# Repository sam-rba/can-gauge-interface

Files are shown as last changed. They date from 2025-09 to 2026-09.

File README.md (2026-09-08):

# Analog Gauge Driver with CAN Interface

Automotive electronic device that drives up to six analog gauges using data from a CAN bus.

## Contents

- `hw/` — Hardware; KiCad files for the PCB.
- `fw/` — Firmare that runs on the PIC microcontroller.
- `sw/` — Software for flashing calibration files onto the device.
- `doc/` — Documentation.

## Features

### Interfaces
- CAN 2.0B interface, up to 500kbps
- Flexible CAN encoding scheme, configurable via CAN

### Outputs
- 1 tachometer output
- 1 speedometer output
- 4 analog outputs (0–5V)

### Power supply
- 9–16V DC input

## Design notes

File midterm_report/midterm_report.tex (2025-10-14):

\documentclass{article}
\usepackage{graphicx}
\usepackage{hyperref}
\usepackage[backend=biber]{biblatex}
\usepackage{amsmath}

\title{\textsc{Comp} 490 Mid-Term Report}

\author{Sam Anthony 40271987 \\
sam@samanthony.xyz \\ s\_a365@concordia.ca
\and
Hovhannes Harutyunyan, PhD \\
Department of Computer Science and Software Engineering \\
haruty@encs.concordia.ca
\and
Concordia University \\
}

\addbibresource{references.bib}

\begin{document}

\maketitle
\tableofcontents
\pagebreak

\section{Project introduction}

The goal of the project is to build an electronic device for use in cars: it is an interface between the car's CAN bus (controller area network) \cite{can20b}, and some analog gauges installed in the cockpit.
An overview of the system is shown in Figure \ref{fig:system}.

\begin{figure}
	\centering
	
	\caption{System diagram.}
	\label{fig:system}
\end{figure}

\section{Desiderata}

The device must be able to perform certain functions.
As well, there are some desirable properties that it should fulfil.

These function and desirable properties are as follows:

\begin{enumerate}
	\item{Receive standard and extended CAN frames from the bus.}
	\item{Decode information in the frames.}
	\item{Generate four analog 0--5V signals suitable for driving temperature or pressure gauges.}
	\item{Generate two variable-frequency square waves for a tachometer and a speedometer.}
	\item{Be user-programmable for any encoding scheme and gauge combination.}
	\item{Run on a 12V automotive electrical power supply.}
	\item{Operate reliably in an automotive environment: resist heat, vibration, and EMI (electromagnetic interference).}
\end{enumerate}

\section{Component selection}

A car is a harsh environment for an electronic device.
The device is subject to large variations in temperature, vibration, and EMI.
To increase reliability, AEC-certified parts were chosen wherever possible.

\subsection{Logic control}

The microcontroller is at the heart of the design.
A Microchip PIC16F1459 was chosen because of its simplicity and robustness, its feature set, and its low cost \cite{pic16f1459}.
It is an 8-bit microcontroller that features a USB peripheral for communicating with the host PC, an SPI peripheral for communicating with the other ICs, and timers for waveform generation.
The PIC is a proven design that Microchip recommends for automotive applications.
It is available in a DIP package, making it convenient for prototyping on a breadboard (Figure \ref{fig:pic}).

\begin{figure}
	\centering
	
	\caption{Microchip PIC16F1459 8-bit microcontroller.}
	\label{fig:pic}
\end{figure}

A Microchip MCP2515 serves as the CAN controller \cite{mcp2515}.
It supports CAN 2.0B up to 1Mbps and it has an SPI interface for communicating with the PIC.
An MCP2561 transceiver goes along with it \cite{mcp2561}.
Like the PIC, both these chips are available in DIP packages for prototyping on the breadboard.

\subsection{Data storage}

The EEPROM is used to store the configuration.
This includes the encoding scheme that defines how parameters are encoded in CAN frames, as well as a table that maps parameter values to output signal values.

There are six such tables: one for each gauge.
Each table has 32 entries, and the mapping is between 16-bit words.
Thus, the required size is $6 \times 32 \times 16 \times 2 = 6144$ bits, or 768 bytes.
The encoding schemes will take a handfull of bytes per gauge in addition.

a Microchip 25LC160C EEPROM was selected.
Its 16Kib (2KiB) of space is more than adequate to hold the configuration.

\subsection{Input/output}

The PIC has an integrated USB peripheral for communicating with a host computer.
The configuration is sent to the PIC via USB and stored on the EEPROM.

Four DACs (digital-to-analog converters) generate analog signals to drive the four pressure or temperature gauges.
Based on the characteristics of commonly-used pressure and temperature sensors \cite{bosch_pst}, it was determined that a resolution of 15mV/step was required.
Given the operating voltage of 5V, this meant that the DACs must have at least $5\text{V}/15\text{mV} \approx 333$ steps of resolution.
Thus, an 8-bit DAC with 256 steps would be insufficient, and so a 10-bit DAC was selected: namely a Microchip\footnote{It is purely a coincidence that all the ICs ended up being Microchip parts. I don't have any particular affinity to the company. It just so happens that they make all the right chips for this particular application.} MCP4912.
The MCP4912 incorporates two DACs in a single chip, so there are two chips per board.

\subsection{Power supply}

The ICs require a 5V supply.

A 12V automotive electrical system operates in a wide range of approximately 9--16V, with a nominal voltage of $\sim$13.7V.
The voltage ripple is often quite significant as well.
Thus, the power supply must be very robust to supply a stable voltage to the ICs.

The voltage drop $V_\text{Drop} = V_\text{In} - V_\text{Out}$ is $16\text{V} - 5\text{V} = 11\text{V}$ in the worst case.
This ruled out the use of a linear regulator, since it would dissipate too much power.
The power dissipation of a linear regulator is linear in $V_\text{Drop}$:

\begin{equation}
	P = (V_\text{In} - V_\text{Out}) \times I
\end{equation}

The load current is estimated to be $\le 250$mA \cite{power_budget}.
That means a linear regulator would dissipate up to $11\text{V} \times 0.250\text{A} = 2.75$W.
That amount of power from a single chip would be difficult to cool.
Thus, a switching regulator is the right choice for this design.

The downside of a switching regulator is that it produces a lot of noise in the PDN (power distribution network).
To isolate the other components from this noise, a two-stage PDN is used.
The first stage is the switching regulator itself, also known as a buck converter.
The buck drops the voltage from 12V down to 7V.

The second stage is composed of two linear regulators: one for the digital circuitry, and one for the analog circuitry.
The linear regulators drop the voltage from 7V down to the final 5V that the ICs require.

Just like a buck converter, switched digital ICs introduce noise into the PDN.
Therefore, it is good practice to keep the digital and analog components separate.
The second power stage isolates the ICs from the noisy buck converter, and splitting the stage between two regulators keeps the digital and analog circuits isolated from one-another.
This design is certainly overkill for the application, but it is better than using too weak of a PDN that delivers an unstable voltage.

The buck converter is a Texas Instruments TPS5430 \cite{tps5430}.
It is surrounded by a couple of LC and RC networks to regulate the voltage and to dampen the output ripple.
See the datasheet and \cite{power_supply} for the process of selecting the accompanying passive components.
The linear regulators are a pair of ST L78M05ABs \cite{l78m}.

\section{PCB design and manufacture}

KiCad was used to design the schematic (Figure \ref{fig:schematic}) and the PCB (Figures \ref{fig:pcb_pours} \& \ref{fig:pcb_3d}).
JLCPCB was chosen to manufacture the printed circuit board.
At the time of writing, the board design has been finalized and submitted to JLC for manufacturing.
It should arrive any day now.

\begin{figure}
	\centering
	
	\caption{Schematic.}
	\label{fig:schematic}
\end{figure}

\begin{figure}
	\centering
	
	\caption{PCB front and back copper pours; drill holes.}
	\label{fig:pcb_pours}
\end{figure}

\begin{figure}
	\centering
	
	\caption{3D render of the PCB.}
	\label{fig:pcb_3d}
\end{figure}

The board is a 4-layer design that uses a combination of surface-mount (SMD) and through-hole (THT) components.
The top and bottom layers are for signals, and the two middle layers are solid ground planes.
This ensures that all signal traces' fields are tightly coupled to ground directly above or below.
Power is routed on the bottom layer.

As mentioned above, most of the ICs are available in DIP (through-hole) packages, and I have been using them for prototyping on the breadboard (Figure \ref{fig:breadboard}).
Once the PCB arrives, I can transplant the chips into the board, along with the passive components.

\begin{figure}
	\centering
	
	\caption{Breadboard circuit for MCP2515 system testing.}
	\label{fig:breadboard}
\end{figure}

The power supply parts, on the other hand, are SMD.
It is important to minimize loop lengths in power supply circuits.
That is why power regulator chips are generally only available in smaller SMD packages.
The SMD components will be assembled by JLC, as I have neither the equipment nor the skill for SMD soldering.

The board was layed out with PCB design best-practices in mind.
Traces are widely-spaced to reduce coupling.
All signal vias are accompanied by a ground via to keep the electric fields from spreading in the dielectric.
All traces are microstripped above a solid ground plane, again to keep the fields tight and to give the current a return path.
The noisy switching regulator is placed far away from the other components to reduce EMI---the sensitive analog signals and the DACs are on the opposite side of the board.

\section{Firmware}

Firmware is the program that runs on the PIC microcontroller.
It is responsible for interacting with the peripherals and transforming data from the CAN bus into output signals for the gauges.

The firmware is written in C for Microchip's XC8 compiler \cite{xc8}.

Each peripheral---MCP2515, 25LC160C, and MCP4912---has a corresponding translation unit.
So far, I have written and tested the MCP4912 DAC unit.
The 25LC160C and MCP2515 units are mostly written but still require more testing.

The firmware must also communicate with a PC via USB.
The Microchip MLA USB library is employed for this purpose \cite{mla_usb}.
However, the USB code uses a lot of the PIC's flash memory.
Some system test builds already fail to link due to lack of space.
As a result, USB may have to be dropped from the project, and another method will have to be devised for programming the user configuration into the EEPROM.
This is a major disappointment, but I will have to work around it seeing as the hardware has already been finalized.

\section{Software}

Software is any program that runs on a host PC, as opposed to on the microcontroller.

I wrote a program called \texttt{usbcom} that communicates with the PIC via USB \cite{usbcom}.
It connects its standard input to the OUT USB endpoint, and its standard output to the IN USB endpoint.
It is written in Go, and uses libusb.

\texttt{usbcom} and the PIC firmware communicate using a proprietary text-based protocol over the USB CDC (communications device class) interface.
The message format is defined using EBNF \cite{protocol}.
The semantics are a simple request-reply arrangement.

I also wrote a Python script---\texttt{bittiming.py}---to calculate CAN bit timing parameters for the MCP2515 \cite{bittiming_py}.

\section{Next steps}

When the board arrives, I will do a visual inspection to ensure that nothing went wrong during manufacturing.
Then I will solder the THT components in place.
Once that is done, I will test the board for continuity and shorts.
With a fully assembled board, I can flash the firmware and migrate system testing from the breadboard to the printed prototype board.
I will finish developing the rest of the firmware, and run through the full suite of system tests that I will have at that point.

I bought some equipment for testing and debugging the system.
A USBtin USB/CAN interface will allow me test the reception of CAN frames \cite{usbtin}.
The EspoTek Labrador is a combined power supply, oscilloscope, and logic analyzer \cite{espotek_labrador}.
It will be used for powering the board and debugging the SPI lines.

If I have time, I would also like to do some experiments with the power supply to see how it handles changes in input voltage.

\printbibliography

\end{document}

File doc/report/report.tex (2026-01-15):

\documentclass[lettersize,conference]{IEEEtran}
\usepackage{biblatex}
\usepackage{hyperref}
\usepackage{graphicx}
\usepackage{subfigure}
\usepackage{pgfgantt}
\usepackage{amsmath,amssymb}
\usepackage{placeins}

\addbibresource{../references.bib}

\title{
	Analog Gauge Driver with CAN Interface \\
	\large \textsc{Comp} 490 Final Report \\~\\
	December 16, 2025
}
\author{
	\IEEEauthorblockN{Sam Anthony}
	\IEEEauthorblockA{Concordia University\\
		Montréal Québec, Canada\\
		Student ID: 40271987\\
		Email: sam@samanthony.xyz}
	\and
	\IEEEauthorblockN{Supervised by Hovhannes Harutyunyan, PhD}
	\IEEEauthorblockA{Concordia University\\
		Department of Computer Science and Software Engineering\\
		Montréal Québec, Canada\\
		Email: haruty@encs.concordia.ca}
}

\begin{document}

\maketitle
\thispagestyle{plain} % enable page numbers
\pagestyle{plain}

\begin{abstract}
	An electronic device is developed that allows analog needle gauges to be retrofitted into a car's EMS (engine management system) while leveraging the capabilities of its CAN (controller area network) bus.
	The proceedings of the project are reported-on, including hardware design, firmware and software development, and testing.
	Finally, the outcomes of the project are assessed against the initial goals, with the overall conclusion being positive.
\end{abstract}

\tableofcontents

\section{Introduction} \label{section:Introduction}

Combustion engines, such as those used to power passenger cars, require precise control over their operation in order to run efficiently and reliably.
Since the early 1970s, car engines have been electronically controlled by an EMS (engine management system) \cite{JapanSemi}.
An EMS is an embedded system consisting of an ECU (electronic control unit), sensors, and actuators.
The actuators include fuel injectors and spark plugs.
The sensors measure crankshaft angle, intake manifold pressure, coolant temperature, and so on.
The ECU features a microcontroller that uses feedback from these sensor data to operate the actuators, thus allowing the engine to run.

Sensor data are used not only by the ECU, but also by a display system mounted in the cabin that allows the driver to monitor the engine's health.
The display system is typically a set of gauges showing, for instance, engine speed, oil pressure, and coolant temperature, among other things.

The display system must visually encode sensor data and convey them to the driver.
Each datum represents the instantaneous value of a continuous quantity---speed, temperature, pressure, etc.
The data are most effectively represented by a graduated radial analog scale with the instantaneous value marked on said scale \cite{Panchal2025}.
The graduated scale takes advantage of vernier acuity: our ability to discern slight misalignment between line segments \cite{Strasburger2018}, while the radial marker leverages the hypercolumnar acuity of vision: our ability to detect minute changes in angle of line segments \cite{Hubel1962}.
Simply put, an analog needle gauge is the best way to display information to the driver.
That is why even modern digital display systems are often skeuomorphs of analog gauges, as seen in Fig.~\ref{fig:Stack}.

\begin{figure}
	\centering
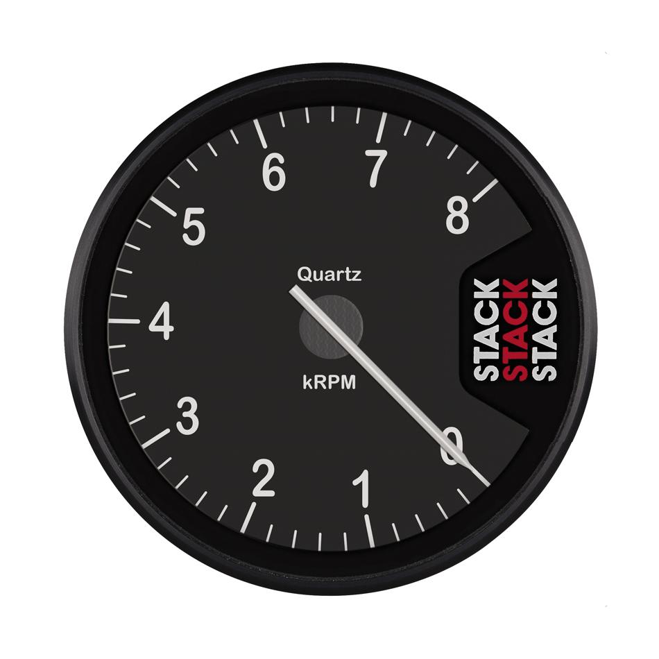
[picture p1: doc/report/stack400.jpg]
	\subfigure[]{ \label{subfig:Stack400}}
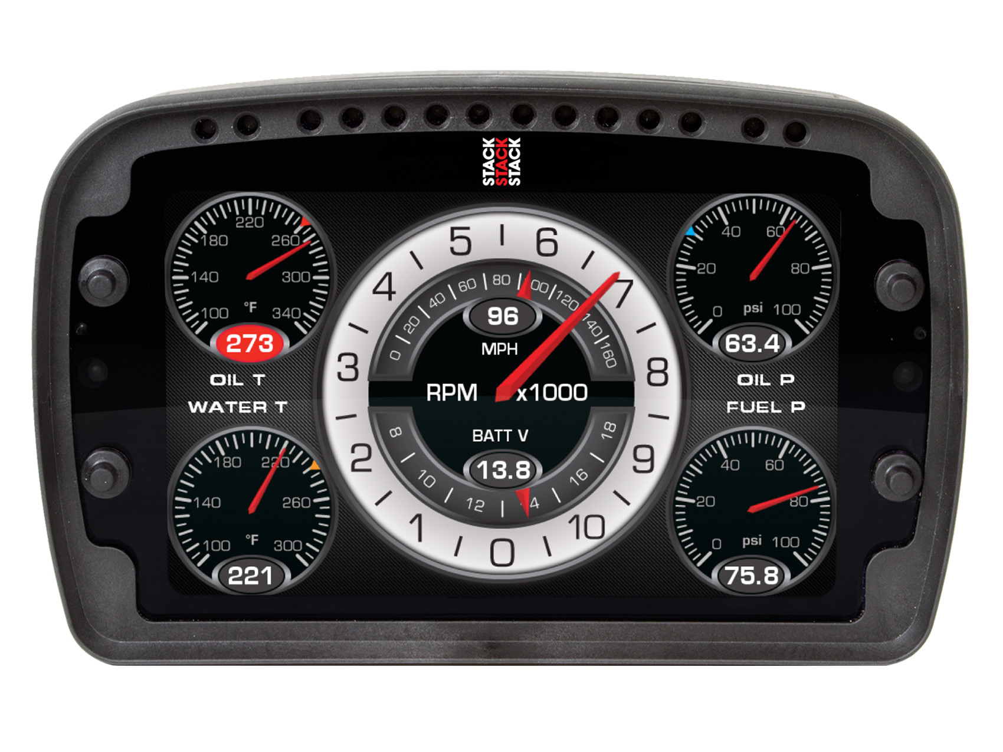
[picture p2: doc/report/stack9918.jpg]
	\subfigure[]{ \label{subfig:Stack9918}}
	\caption{\subref{subfig:Stack400} Analog needle gauge \cite{Stack400} and; \subref{subfig:Stack9918} skeuomorphic digital display emulating analog gauges \cite{Stack9918}.}
	\label{fig:Stack}
\end{figure}

As engine performance increases, the operating window where it will run reliably shrinks, necessitating even tighter control.
This spurs demand for even more sensor data, both for the ECU---to precisely regulate the running of the engine---and for the driver, to monitor the engine's health and to ensure that it stays within its safe operating window.

This is especially true in racing, where the engine must be fine-tuned to its limits while remaining reliable for the duration of its life.
Race teams often fit additional sensors and gauges to the car in order to monitor the health of the engine (Fig.~\ref{fig:R31}).

\begin{figure}
	\centering
	
	\caption{Analog gauges fitted to 1987 Nissan Skyline GTS-R Group A race car \cite{r31}.}
	\label{fig:R31}
\end{figure}

All these sensor data must somehow be transmitted throughout the car; a computer network handles this task well.
CAN (controller area network) \cite{can20b} is ubiquitous: introduced by Bosch in the early 1990s and standardized by ISO 11898 \cite{CanHistory}, all cars sold in the United States are required to be equipped with a CAN bus \cite{CFR40.86.1806-05}.

Most modern digital display systems, such as the one shown in Fig.~\ref{subfig:Stack9918}, come with a CAN interface, allowing them to display a practically unlimited array of information from whatever sensors may be equipped to the car.
On the other hand, analog gauges have largely been abandoned by manufacturers, as digital panels can display myriad information at a fraction of the cost of an equivalent set of analog gauges.
However, some, including myself, prefer a genuine analog gauge as opposed to a facsimile displayed on a screen.
The trouble is, most analog gauges lack a CAN interface, with only a few companies making CAN-enabled analog gauges, mostly for industrial applications \cite{Vdo}.

Those who wish to install an analog gauge typically do so by installing a sensor on the engine and running a wire directly to the gauge's analog input---this is the setup recommended by most gauge manufacturers \cite{Stack3307Manual}.
While this does work, it is less than ideal for several reasons.

Firstly, running a wire through the engine bay leaves the signal vulnerable to EMI (electromagnetic interference) as it travels near noisy components like the ignition coils.
This can cause signal integrity issues that can otherwise be avoided by transporting the signal via the CAN bus that the car is likely to have already---CAN uses a CRC (cyclic redundancy check) to provide data integrity.

Secondly, the EMS already features a host of sensors, and installing another for the gauge often leads to duplication.
While this may appear to provide redundancy, it in fact does not.
On the contrary, it reduces reliability and increases complexity by introducing additional failure points into the system.
A properly engineered solution would integrate the gauge into the EMS, allowing them to share sensor data, thus reducing the complexity of the system.

This brings us finally to the subject of the report: a device that allows analog gauges to be retrofitted into a car while leveraging the capabilities of the CAN bus already present in the vehicle.

\section{Project Overview} \label{section:ProjectOverview}

At a high level, the device acts as an interface between the car's EMS and the analog gauges in the cabin.
It receives sensor data encoded in CAN frames from the ECU, and transforms them into signals that the gauges can understand: such as a variable-frequency square wave for a tachometer, or a 0--5V analog signal for a pressure gauge.
Thus, it is referred to as an \emph{analog gauge driver with a CAN interface}.

A block diagram of the system is shown in Fig. \ref{fig:BlockDiagram}.
The device has a CAN controller and transceiver for sending and receiving CAN frames.
A microcontroller decodes and extracts sensor data from the frames, and communicates the data to the peripherals which drive the gauges.
Two dual DACs (digital-to-analog converters) generate signals for the four analog outputs.
These can drive up to four temperature or pressure gauges, or any gauge that accepts a 0--5V analog input.
The microcontroller's timers produce two variable-frequency square waves which drive the tachometer and speedometer.

\begin{figure}
	\centering
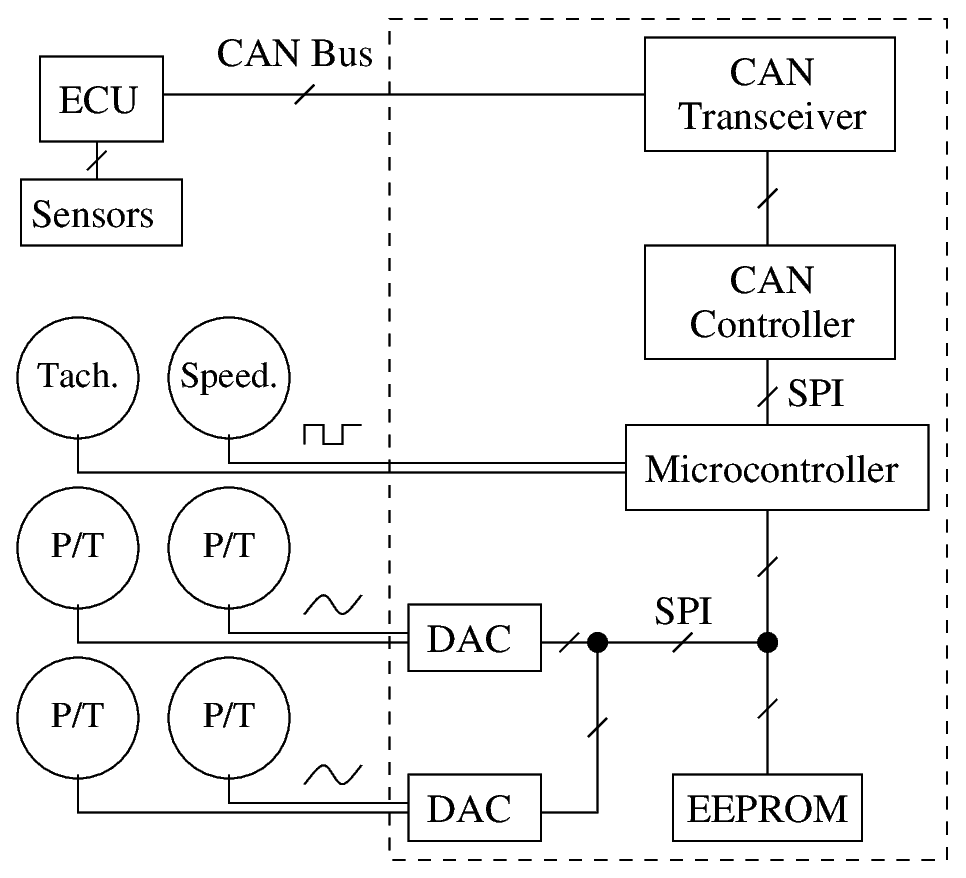
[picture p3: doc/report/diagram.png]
	
	\caption{System diagram.}
	\label{fig:BlockDiagram}
\end{figure}

As it is intended to be a generic part that can be retrofitted to existing cars, the device must work with any combination of sensors, gauges, and CAN encoding schemes.
Thus, it is user-programmable, allowing it to be installed in any system.
The user-calibration is programmed via CAN and stored in non-volatile memory, namely an EEPROM (electrically erasable programmable read-only memory) chip.

The project consisted of four tasks that were completed concurrently over the course of the term.
The timeline of the project is shown in Fig. \ref{fig:Timeline}.
The tasks to be completed were hardware design, firmware development, software development, and testing.
Each of these topics are covered in the subsequent sections.

\begin{figure*}[p]
	\centering
	\begin{ganttchart}[
		x unit=0.055in,
		y unit title=0.3in,
		y unit chart=0.275in,
		newline shortcut=true,
		bar label node/.append style={align=left},
		milestone label node/.append style={align=left},
		vrule label node/.append style={align=center},
		time slot format=isodate
	]{2025-09-01}{2025-12-18}
		\gantttitlecalendar{year, month=name} \\

		\ganttgroup{Hardware}{2025-09-01}{2025-10-22} \\
		\ganttbar{PCB design}{2025-09-01}{2025-10-01} \\
		\ganttlinkedbar{Manufacturing}{2025-10-01}{2025-10-15} \\
		\ganttlinkedbar{Board testing}{2025-10-15}{2025-10-22} \\
		\ganttlinkedmilestone{Board completed}{2025-10-22} \\

		\ganttgroup{Firmware}{2025-09-04}{2025-11-10} \\
		\ganttbar{Main}{2025-09-04}{2025-11-10} \\
		\ganttbar{DAC}{2025-10-02}{2025-11-08} \\
		\ganttbar{EEPROM}{2025-10-02}{2025-11-08} \\
		\ganttbar{CAN}{2025-10-03}{2025-11-08} \\
		\ganttmilestone{Migrate to board}{2025-10-22} \\
		\ganttbar{Calibration}{2025-10-24}{2025-11-08} \\
		\ganttbar{Serialization}{2025-11-01}{2025-11-08} \\
		\ganttbar{Decoding}{2025-11-01}{2025-11-08} \\
		\ganttbar{Tach./speedo.}{2025-11-10}{2025-11-10} \\

		\ganttgroup{Software}{2025-10-03}{2025-11-10} \\
		\ganttbar{CAN timing script}{2025-10-03}{2025-10-04} \\
		\ganttbar{Calibration software}{2025-11-07}{2025-11-10} \\

		\ganttgroup{Testing}{2025-09-04}{2025-11-10} \\
		\ganttmilestone{First SPI test}{2025-10-02} \\
		\ganttmilestone{First DAC test}{2025-10-02} \\
		\ganttmilestone{First EEPROM test}{2025-10-02} \\
		\ganttmilestone{First CAN test}{2025-10-23} \\
		\ganttmilestone{First calibration}{2025-11-08} \\
		\ganttmilestone{First tach./speedo.\ganttalignnewline{}signals}{2025-11-10} \\

		\ganttgroup{Documentation}{2025-09-01}{2025-12-18} \\
		\ganttbar{Power supply}{2025-09-07}{2025-09-27} \\
		\ganttbar{Midterm report}{2025-10-13}{2025-10-14} \\
		\ganttbar{Cal. frame format}{2025-10-25}{2025-11-08} \\
		\ganttbar{Final report}{2025-12-08}{2025-12-18}

		\ganttvrule{Board completed}{2025-10-22}
	\end{ganttchart}
	\caption{Project timeline.}
	\label{fig:Timeline}
\end{figure*}

\section{Hardware} \label{section:Hardware}

The hardware is a PCB (printed circuit board) hosting a set of ICs (integrated circuits)---the microcontroller and peripherals listed in the previous section (Fig \ref{fig:BlockDiagram})---and some supporting passive components: resistors, capacitors, and an inductor.

\subsection{Component selection} \label{subsection:ComponentSelection}

A car is a harsh environment.
The device is subject to vibration, EMI (electromagnetic interference), and large variations in temperature.
To increase reliability, AEC-certified parts were chosen wherever possible \cite{aec}.

\paragraph*{Microcontroller}
The microcontroller is at the heart of the design.
A Microchip PIC16F1459 was chosen for its simplicity, robustness, feature-set, and low cost%
\footnote{ \label{foot:Usb}
	The PIC16F1459 also features a USB (universal serial bus) interface.
	The original design, as shown in the proposal \cite{proposal}, used USB to program the user-calibration.
	However, later in the project, USB had to be dropped due to memory constraints; now the calibration is programmed via CAN.
	In a future revision of the board, the PIC16F1459 could be replaced with a chip lacking a USB interface in order to reduce cost.}
\cite{pic16f1459}.
It is an 8-bit microcontroller with an SPI peripheral for communicating with the other ICs, and timers for generating the tachometer and speedometer signals.
The PIC is a proven design that Microchip recommends for automotive applications.
It is available in a DIP (dual in-line) package, making it convenient for breadboard prototyping (Fig. \ref{fig:Breadboard}).

\begin{figure}
	\centering
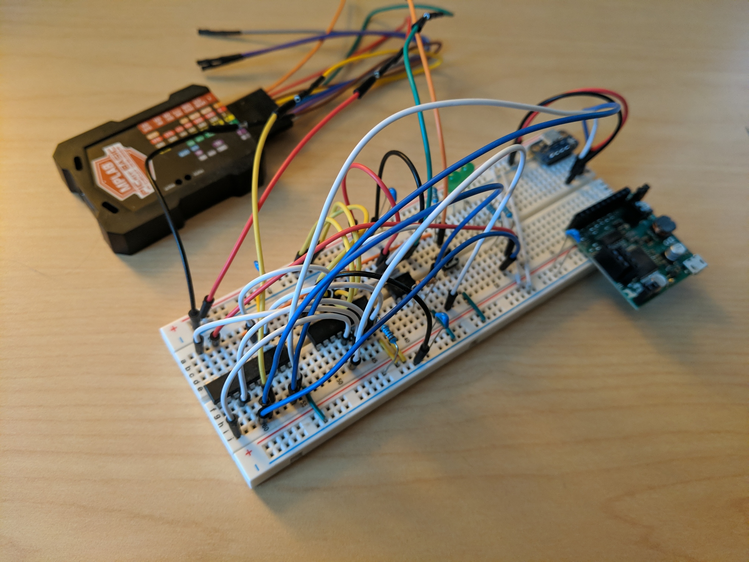
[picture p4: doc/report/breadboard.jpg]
	
	\caption{Breadboard circuit for CAN testing.}
	\label{fig:Breadboard}
\end{figure}

\paragraph*{CAN controller and transceiver}
The CAN controller handles the reception and transmission of CAN frames.
It is complemented by a CAN transceiver which acts as a buffer between the controller's logic level signals and the differential signals on the bus.
A Microchip MCP2515 controller \cite{mcp2515} and MCP2561 transceiver \cite{mcp2561} were chosen to fill these roles.
The MCP2515 supports CAN 2.0B up to 1Mbps and it has an SPI interface for communicating with the PIC.
Both these chips are available in DIP packages for breadboard prototyping.

\paragraph*{EEPROM}
The EEPROM stores the user-calibration that defines how sensor signals are encoded in CAN frames, as well as tables that map sensor readings to output signal values.
A Microchip 25LC160C EEPROM was selected \cite{25lc160c}.
It has an SPI interface, and its 2KiB of space is sufficient to store  the calibration.

\paragraph*{DACs}
Two dual-channel DACs (digital-to-analog converters) drive the four analog outputs of the board.
Based on the characteristics of commonly-used pressure and temperature sensors \cite{bosch_pst}, it was determined that a resolution of 15mV/step was required.
Given the operating voltage of 5V, this meant that the DACs would need at least $5\text{V}/15\text{mV} \approx 333$ steps of resolution.
Thus, an 8-bit DAC with 256 steps would have been insufficient, and so a 10-bit DAC was selected: namely a Microchip MCP4912%
\footnote{
	Perhaps it is worth noting that I have no particular affinity to Microchip as a company.
	It is purely a coincidence that all the chosen ICs ended up being made by them.
	It just so happens that they make good chips for this application.}
\cite{mcp4912}.
The MCP4912 is a dual-channel 10-bit DAC, so two of them are required to drive the board's four analog outputs.

\subsection{Power supply} \label{subsection:PowerSupply}

Standard automotive electrical systems operate at a nominal voltage of around 13.7V, but can swing between 9 and 16V.
The voltage supply often has a strong pulsating component as well, known as ripple.
The board's ICs require a stable 5V to operate reliably.
Hence, the board's power supply is very robust to tolerate the wide input voltage range and to rectify the ripple.

The voltage drop $V_\text{Drop} = V_\text{In} - V_\text{Out}$ is $16\text{V} - 5\text{V} = 11\text{V}$ in the worst case.
This ruled out the use of a linear regulator, since it would dissipate too much power---the power dissipation of a linear regulator is linear in $V_\text{Drop}$: $P = V_\text{Drop} \times I$.
The load current was estimated to be 250mA at most \cite{power_budget}, so a linear regulator would dissipate up to 2.75W.
That amount of power from a single chip would be difficult to cool.
Therefore, a linear regulator was deemed inadequate, necessitating the use of a switching regulator instead.

The downside of a switching regulator is that it introduces noise and ripple into the PDN (power distribution network).
To isolate the other components, a two-stage PDN is used.

The first stage is the switching regulator itself, also known as a buck converter.
It drops the voltage from the car's 9--16V down to an intermediate 7V level.

Just like a buck converter, switching digital ICs introduce noise into the PDN.
Therefore, the second stage is split between two regulators in order to keep the analog and digital circuitry separate.
It is composed of two ST L78M05AB \cite{l78m} LDOs (low-dropout regulators) that bring the voltage from 7V down to the final 5V that the ICs require.

A diagram of the PDN is shown in Fig. \ref{fig:Pdn}.

\begin{figure}
	\centering
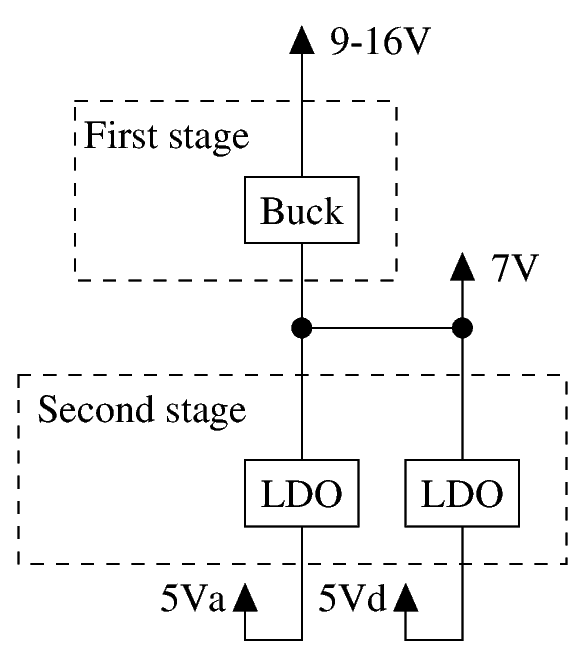
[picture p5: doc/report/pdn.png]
	
	\caption{Power distribution network.}
	\label{fig:Pdn}
\end{figure}

The buck converter in the first stage is a Texas Instruments TPS5430 \cite{tps5430}.
It is accompanied by some RC and LC networks that set the output voltage level and dampen the output ripple.
Unfortunately, the passive component values were calculated incorrectly, which resulted in the buck converter outputting the wrong voltage.
This mistake is discussed further in \S\ref{section:Testing}.

\subsection{PCB design and manufacture} \label{subsection:PcbDesign}

The schematic (Fig. \ref{fig:Schematic}) and PCB (Figs. \ref{fig:PcbPours}, \ref{fig:Pcb3d}, and \ref{fig:PcbAssembled}) were designed in KiCad \cite{kicad}.
JLCPCB manufactured the PCB \cite{jlcpcb}.

\begin{figure*}
	\centering
	
	\caption{Schematic.}
	\label{fig:Schematic}
\end{figure*}

\begin{figure}
	\centering
	
	\caption{PCB front and back copper pours.}
	\label{fig:PcbPours}
\end{figure}

\begin{figure}
	\centering
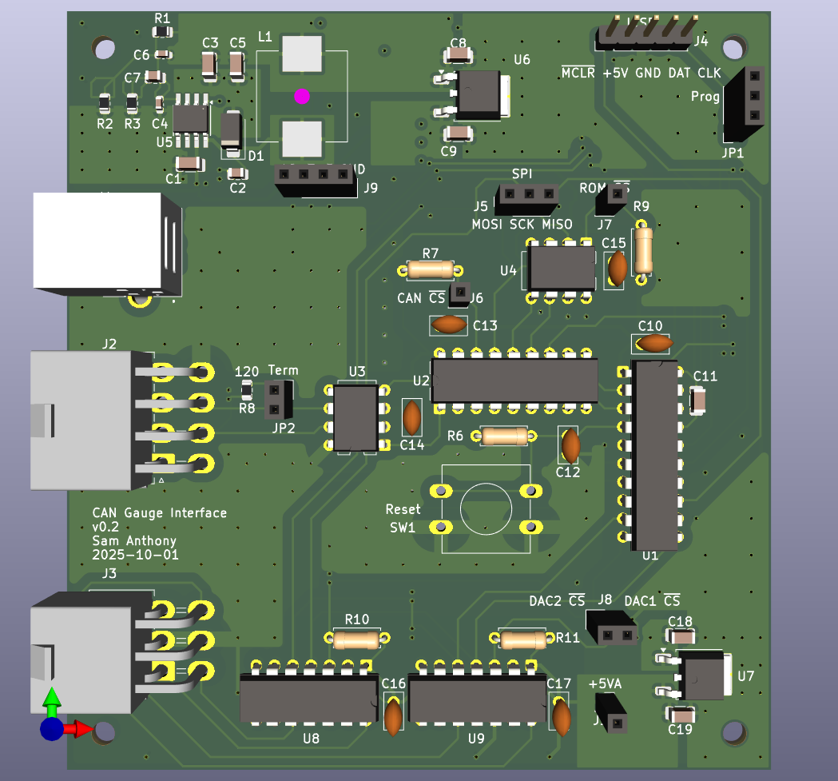
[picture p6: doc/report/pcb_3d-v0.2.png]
	
	\caption{3D render of the PCB. Note the vestigial USB-B connector in the top left, to be removed in a future revision (see footnote \ref{foot:Usb}).}
	\label{fig:Pcb3d}
\end{figure}

\begin{figure}
	\centering
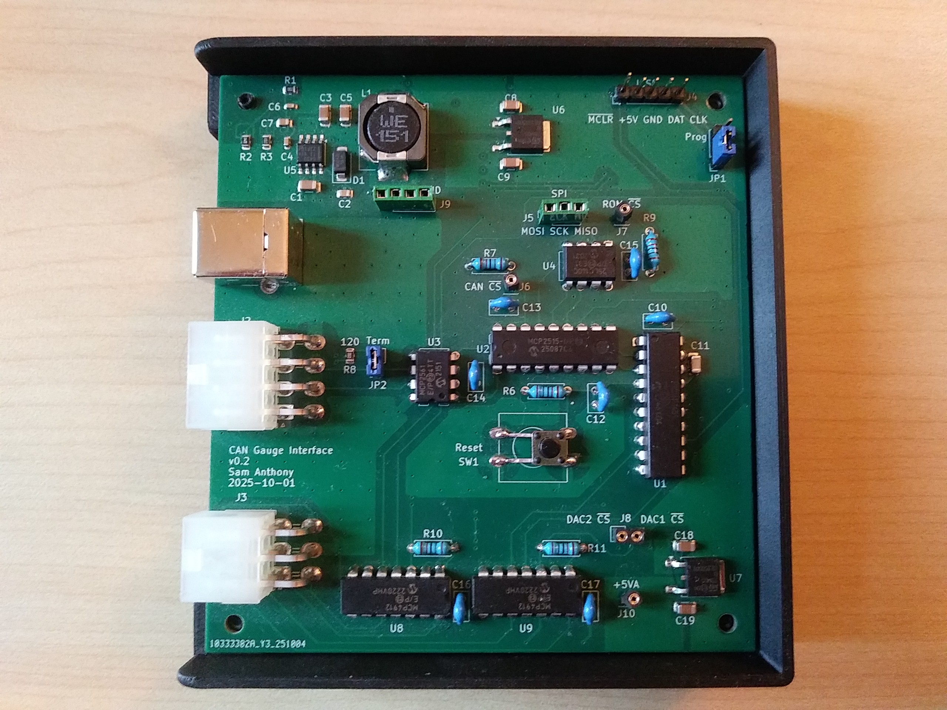
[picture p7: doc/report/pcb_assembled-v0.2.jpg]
	
	\caption{Fully-assembled PCB sitting on 3D-printed stand.}
	\label{fig:PcbAssembled}
\end{figure}

The board was laid out with PCB design best-practices in mind.
It is a 4-layer design that uses a combination of surface-mount (SMD) and through-hole (THT) components%
\footnote{
	Not that mixing SMD and THT components is good practice---it is not.
	The board was only designed this way to allow the DIP parts that were used on the breadboard to be reused on the prototype PCB.}.
The top and bottom layers are for signals, and the two middle layers are solid ground planes; power is routed on the bottom layer.
All traces are microstripped above a solid ground plane to keep the fields tightly coupled and to give the current a low-impedance return path.
All signal vias are accompanied by a ground via, again to keep the fields from spreading out in the dielectric.
Traces are widely-spaced to reduce interference with one another.
The noisy switching regulator is placed far away from the other components to reduce EMI---the sensitive analog signals and the DACs are on the opposite side of the board.

One may notice that the board sports a USB-B connector: a vestige of the original design which used USB for user-calibration, as opposed to CAN which it uses currently (see footnote \ref{foot:Usb}).
The connector is no longer required and will be removed in a future revision.

As mentioned above, most of the chosen ICs are available in DIP (through-hole) packages, and were used for prototyping on a breadboard (Fig. \ref{fig:Breadboard}).
They were then transplanted into the PCB once it had been manufactured (Fig. \ref{fig:PcbAssembled}).
This allowed firmware development to be carried out in parallel on the breadboard while waiting for the PCB to arrive, as the timeline in Fig. \ref{fig:Timeline} shows.

\section{Firmware} \label{section:Firmware}

Firmware is the program that runs on the board's microcontroller.
It is responsible for interacting with the peripherals, decoding CAN frames, and transforming sensor data into output signal levels to drive the gauges.
It is written in ISO~C (C99) \cite{c99}.
The program is compiled for the PIC16F1459 using Microchip's XC8 compiler \cite{xc8}.
In total, the firmware is 1601 lines of C code \cite{repo}.

The firmware is divided into a set of C modules.
Each peripheral (MCP2515, 25LC160C, MCP4912) has a corresponding module (\texttt{can}, \texttt{eeprom}, \texttt{dac}).
Collectively, these are known as the HAL (hardware abstraction layer).

There are also higher-level modules that make use of the HAL.
One example is the \texttt{table} module.
The EEPROM stores several tables that are mappings from sensor-reading-values to output-signal-values.
For example, one table maps engine speed (rpm) to tachometer pulse frequency.
The \texttt{table} module makes use of the \texttt{eeprom} HAL module and provides a simple interface to read and manipulate these tables stored in the EEPROM.

Dependencies between the modules are shown in Fig. \ref{fig:Deps}.

\begin{figure}
	\centering
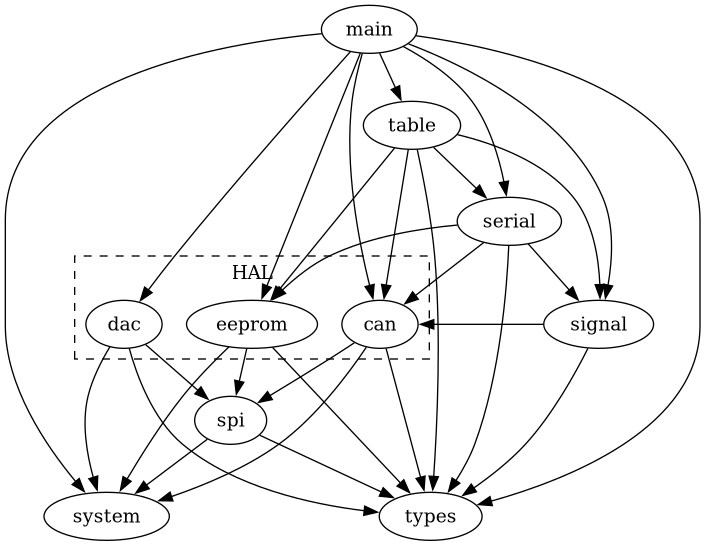
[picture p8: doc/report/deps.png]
	
	\caption{Firmware module dependency graph.}
	\label{fig:Deps}
\end{figure}

The \texttt{main} entry point of the firmware simply initializes the HAL and waits to receive an interrupt from either the CAN controller or a timer.

The ISR (interrupt service routine) handles the reception and decoding of CAN frames.
Upon receiving a frame, the ISR decodes the sensor signal contained therein, and looks up the corresponding output signal value in the mapping table.
It then directs one of the peripherals to generate the appropriate output signal accordingly.
For instance, it may instruct one of the DACs to change the voltage being driven to a temperature/pressure gauge, or it may set the period of the tachometer wave.

The variable-frequency square waves that drive the tachometer and speedometer are generated using the PIC's built-in timer peripherals.
Upon overflow, the timers trigger the ISR to toggle the appropriate GPIO (general-purpose input/output) pin.
The waves' frequencies are controlled by setting the timers' periods.

\subsection{Calibration} \label{subsection:FwCalibration}

In order for the device to work with any combination of sensors, gauges, and CAN encoding schemes, it must be configurable by the end-user.

The user-calibration defines the mapping between sensor readings and output signal values that drive the gauges.
It also defines how sensor readings are encoded in CAN frames.

The \texttt{signal} module defines a data structure that specifies the format of a sensor reading, or \emph{signal} as it is known in the DBC format \cite{dbc10}, within the payload of a CAN frame.
This includes the CAN ID of the carrier frame, the size and offset of the signal within the frame's payload, and the byte order of the signal.

The format of each signal is stored in the EEPROM as part of the user-calibration.
The calibration includes six signals: tachometer, speedometer, and the four analog channels.

The user-calibration is programmed onto the board via special CAN frames, called \emph{calibration} or \emph{control} frames.
There are two control frames, each with a unique ID.
The first is the \emph{table control frame} which is used to read or write rows of the mapping tables.
The second is the \emph{signal control frame} which is used to read or write the encoding format of each signal.
These control frames are defined in full by the \emph{calfmt} document in the project's source repository \cite{calfmt}.

When the device receives a control frame, the ISR decodes it and either, in the event of a write-request, updates the appropriate segment of the calibration in the EEPROM; or in the event of a read-request, reads the appropriate segment and responds by sending it back in a CAN frame.
This allows the calibration to be flashed onto the board using write requests and verified using read requests.
The calibration is sent to the device from a personal computer running the calibration software, which is discussed in the next section.

\section{Software} \label{section:Software}

In addition to the firmware, several other pieces of software were developed over the course of the project.
In contrast with the firmware which runs on the device's microcontroller, these programs target a personal computer.

\subsection{Calibration software} \label{subsection:SwCalibration}

As described above, the user-calibration, stored in the board's EEPROM, allows the device to be configured for any combination of sensors, gauges, and CAN encoding schemes.

The \emph{cal} program flashes the calibration from a personal computer onto the device via the CAN bus \cite{Cal}.
Cal takes a set of files containing the user-calibration as input, and outputs CAN frames that are sent to the device.
These are the special \emph{control} frames mentioned in \S\ref{subsection:FwCalibration} and defined fully in \cite{calfmt}.

The calibration is represented by a DBC file \cite{dbc10} and a set of CSV files.
The DBC file specifies the CAN encoding scheme which defines how sensor readings, called \emph{signals} in the DBC file, are encoded into CAN frames.
The DBC file can specify one signal for each gauge, e.g., \texttt{EngineSpeed} for the tachometer, \texttt{EngineOilPressure} for one of the analog gauges, and so on, each with a corresponding CAN ID and encoding format.
This allows the device to be configured for the CAN encoding scheme that the car's EMS uses.

The CSV files define the tables that map sensor-reading-values to output-signal-values.
There is one table, and thus one CSV file, for each signal.
This allows the device to be configured for the particular sensors and gauges installed in the car.

Cal is written in 674 lines of Go \cite{Golang}.
It uses the Linux kernel's SocketCAN \cite{SocketCan} facility to access the CAN bus.
Thus, its support is limited to Linux only.
Ideally it should be ported to other operating systems in the future.

\subsection{CAN bit timing calculation} \label{subsection:Bittiming}

The second program is a small script for calculating CAN bit timing parameters.

Each node in a CAN network has its own clock generator.
The bit timing parameters can be configured individually at each node in order to achieve a common bit rate throughout the network even though the nodes' clock periods may be slightly out of sync \cite{CanBitTiming}.

The script, named \texttt{bittiming.py} \cite{BitTimingScript}, calculates a set of valid combinations of timing parameters for a given clock frequency and bit rate.
It displays these parameter combinations in the form of configuration words for the MCP2515 CAN controller.

The configuration words are hard-coded in the firmware and are written to the MCP2515's configuration registers at startup time.
Although the bit rate is currently a constant set at compile time, the firmware includes several sets of bit timing configuration words, one for each commonly-used bit rate as defined by CANopen \cite{CanBitrates}.
This is to facilitate the addition of an automatic baud rate detection algorithm to the firmware at a later date.

A flaw in the board was discovered while calculating the bit timing parameters.
The CAN controller requires an external oscillator.
On the prototype board, the CAN controller's clock input is connected to the microcontroller's clock output which runs at 12MHz.
12MHz is not fast enough to run a bit rate of 800kbps or greater.
Therefore, although the MCP2515 supports bit rates up to 1Mbps, the board is limited to 500kbps with the current clock setup.
This can be remedied in a future revision by adding a dedicated 20MHz oscillator for the CAN controller.

\section{Testing} \label{section:Testing}

A suite of tests was developed to verify the functionality of the device.
Each system test is a standalone firmware image designed to test a particular subsystem.
For example, there are system tests for the CAN, DAC, and EEPROM modules, and for the tachometer and speedometer signal generation systems.
There are also several unit tests to verify some of the more complex routines, such as the CAN decoding functions.
The tests were used continually throughout the project to check the functionality of each firmware module as they were being developed, and to detect regression as changes were made and new modules added.

\subsection{Equipment} \label{subsection:TestEquipment}

Some special equipment was required for testing.

A USBtin USB-to-CAN interface enabled reading and writing CAN frames to the bus from a workstation computer \cite{usbtin}.
It was used to monitor the bus during CAN system testing, and to flash the user-calibration onto the device.

An EspoTek Labrador is an inexpensive all-in-one oscilloscope, signal generator, power supply, and logic analyzer \cite{espotek_labrador}.
It proved invaluable during testing.
The power supply provided 12V to the board.
The logic analyzer was used to debug the SPI (serial peripheral interface) bus while developing the HAL firmware modules.
And the oscilloscope was used to measure the tachometer and speedometer signals generated by the device.

Finally, a simple multimeter was used for continuity testing to verify the design of the circuit board, and to measure the voltages of the board's analog outputs during system testing.

\subsection{Results} \label{subsection:TestResults}

An issue with the power supply was uncovered while testing the circuit board.
As mentioned in \S\ref{subsection:PowerSupply}, the first stage of the power supply is supposed to output 7V.
However, upon receiving the board, this rail measured only 5V, revealing a mistake in the calculation of the passive components surrounding the buck converter that control its output voltage.
While this issue will have to be corrected in a future revision, it did not prevent the existing board from being used for the remainder of the project.
Bypassing the second stage of the power supply by jumping the 7V and 5V rails, thus providing the ICs with the correct voltage, allowed the board to function well enough.
This workaround can be seen in Fig. \ref{fig:TestSetup}.

\begin{figure}
	\centering
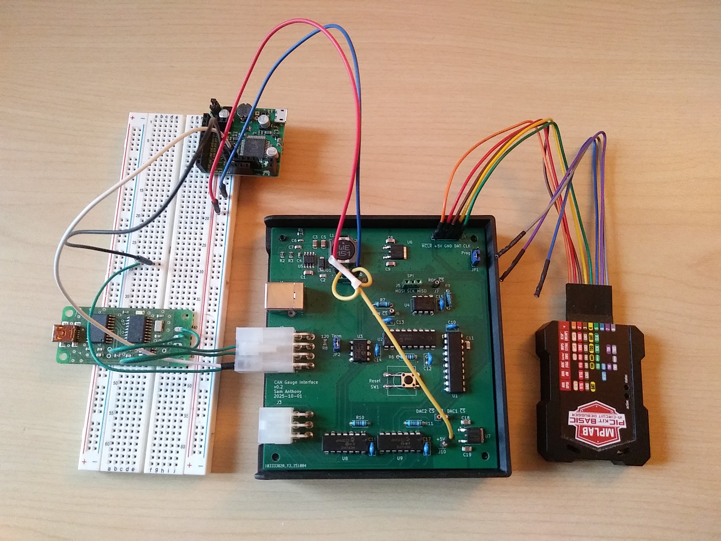
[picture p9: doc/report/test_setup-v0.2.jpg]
	
	\caption{%
		Testing setup: EspoTek Labrador (top), USBtin (left), gauge driver (center), PIC programmer (right).
		Yellow wire jumps the 7V, 5V-analog, and 5V-digital rails, providing power to the board and circumventing the flaw in the first stage of the power supply.}
	\label{fig:TestSetup}
\end{figure}

Overall, testing has been successful.
Despite minor flaws in the board, the device is able to perform all of its duties.
It is able to receive CAN frames from the bus, decode them, and generate signals to drive up to six analog gauges accordingly.
It can generate two variable-frequency square waves to drive a tachometer and a speedometer, and four 0--5V analog signals to drive four pressure or temperature gauges.
Furthermore, it can be configured for any combination of sensors, gauges, and CAN encoding schemes by flashing a user-calibration with the \emph{cal} program.

\section{Conclusion} \label{section:Conclusion}

In conclusion, the project was a success; the device fulfills all of its requirements.
What follows is a summary of the goals, proceedings, and outcomes of the project.

The goal was to design an electronic device that would allow analog gauges to be retrofitted into a car's EMS (engine management system) while leveraging the capabilities of the car's CAN (controller area network) bus.
The device transforms sensor reading data from the CAN bus into electric signals suitable for driving the gauges.

In the first phase of the project, the device's hardware was designed: a PCB (printed circuit board) hosting a set of ICs (integrated circuits) that, together as a system, perform the necessary functions of the device.

Firmware---software that runs on the device's microcontroller---was developed to operate the device's hardware.
The firmware is responsible for interacting with the various peripherals on the board, decoding CAN frames, and transforming the sensor data contained therein into output signal values to drive the gauges.

In addition to the firmware, another piece of software was developed: a program for flashing a user-calibration onto the device.
This program, called \emph{cal}, reads the calibration from a set of files and writes it to the device via the CAN bus.
The calibration allows the device to be configured for any combination of sensors, gauges, and CAN encoding schemes that the car's EMS may use.

Both the software and hardware of the device were tested continually over the course of the project.
Suites of unit and system tests were developed to verify the device's subsystems and firmware modules.
Hardware testing revealed some flaws in the board that will have to be fixed in a subsequent revision.
However, they were not catastrophic, and development was able  to proceed using the existing board.

Ultimately, testing confirmed that, despite minor flaws in the board, the device operates correctly and fulfills all of its requirements.
It is able to receive CAN frames from the bus, decode them, and generate signals to drive up to six analog gauges.
Furthermore, it can be configured for any combination of sensors, gauges, and CAN encoding schemes by flashing a user-calibration with the \emph{cal} program.
Hereby the project is considered a success.

\FloatBarrier
\clearpage
\printbibliography
\vfill

\end{document}

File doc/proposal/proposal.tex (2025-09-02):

\documentclass{article}
\usepackage{graphicx}

\title{
Analog Gauge Driver with CAN Interface \\
\large COMP490 Project Proposal
}
\author{
Sam Anthony 40271987 \\
sam@samanthony.xyz \\ s\_a365@concordia.ca
\and
Hovhannes Harutyunyan, PhD \\
Department of Computer Science and Software Engineering \\
haruty@encs.concordia.ca
\and
Concordia University \\
}

\begin{document}

\maketitle

Installing aftermarket gauges in a car typically requires installing sensors as well.
However, such sensors are often already present, and are used by the ECU (engine control unit).
Thus, the installation of aftermarket gauges can result in duplicate sensors which add complexity without augmenting the functionality or reliability of the vehicle.
Sensors installed like this are not redundant.
In fact, they reduce reliability, because each is a single point of failure.

The proposed device allows gauges to use the sensors already on the car.
It retrieves sensor data from the ECU via the CAN bus (controller area network bus) and transforms the data into a format that the gauges can understand: a 0--5V analog signal in the case of a temperature or pressure gauge, or a square wave in the case of a tachometer or speedometer.

The device is an embedded system comprising a microcontroller, a CAN controller and transceiver, several DACs (digital-to-analog converters), and PROM (programmable read-only memory).
The CAN interface is used for retrieving data from the ECU via the bus.
The DACs drive analog signals to the temperature and/or pressure gauges.
The microcontroller has an integrated PWM peripheral for driving a square wave to the tachometer and/or speedometer.
The PROM stores the calibration: a table that maps CAN data values to voltages or frequencies.
The microcontroller has a USB interface for programming the PROM from a computer.

\begin{figure}
	
	\caption{System diagram}
\end{figure}

The project has three parts: hardware design, software development, and testing.
The hardware and software development can be carried out concurrently.
Testing is the final step.

Hardware design involves selecting ICs (integrated circuits), creating a circuit schematic, and designing a PCB (printed circuit board).
Once the board design is finalized, it can be sent for manufacturing.

Two pieces of software must be written.
The first runs on the microcontroller.
Essentially, it must communicate with the various peripherals by transforming and transferring data between them.
It must fetch frames from the CAN controller and decipher them.
The CAN data are used to lookup the output value in the ROM.
Either the PWM peripheral or a DAC is used to send the appropriate signal to the gauge.
The microcontroller uses SPI (serial peripheral interface) to communicate with the peripherals.

The second piece of software runs on the user's computer.
It programs the PROM with calibration data.
It communicates with the microcontroller using a simple text-based protocol over USB.

\end{document}

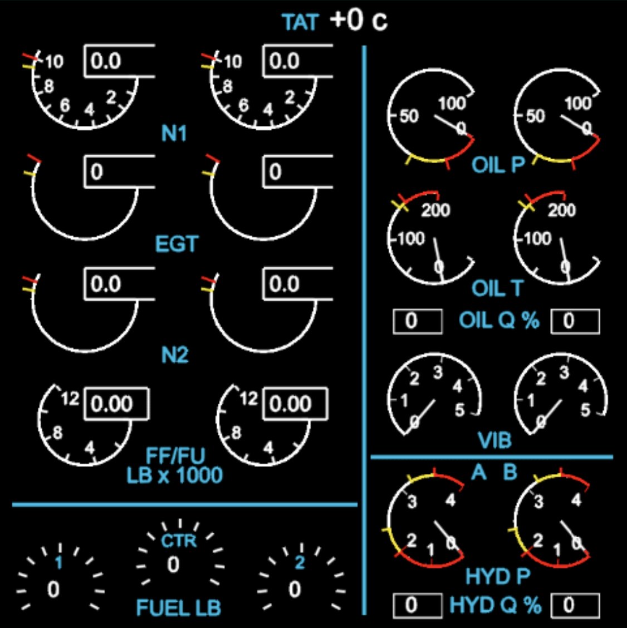
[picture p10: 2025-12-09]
doc/report/boeing.jpeg

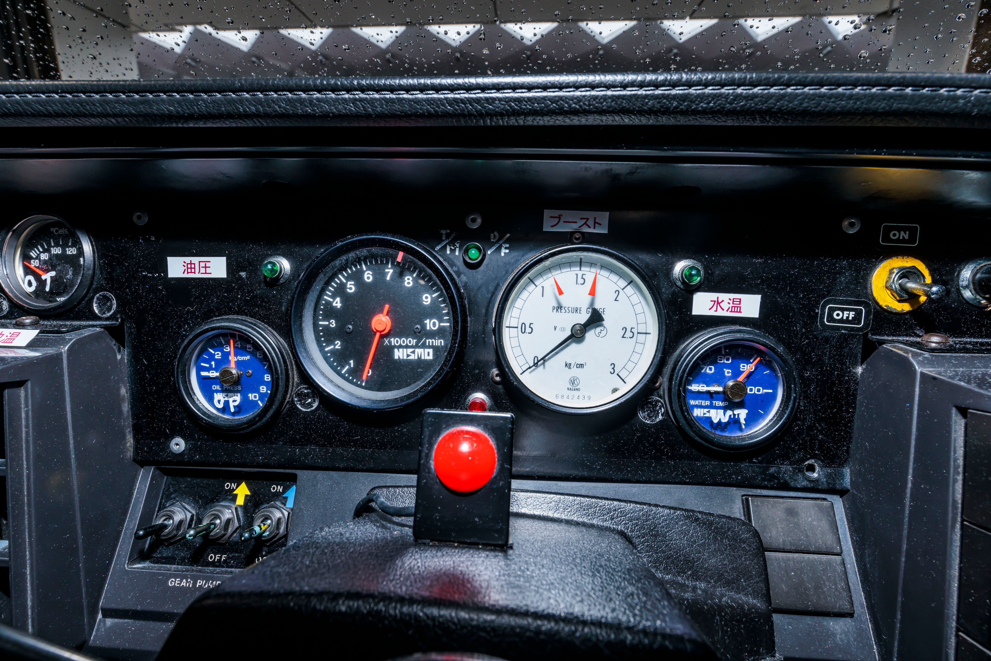
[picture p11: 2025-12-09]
doc/report/r31.jpeg

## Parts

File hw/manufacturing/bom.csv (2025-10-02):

Reference | Qty | Value | DNP | Footprint | Datasheet
C1,C3,C5 | 3 | 22u |  | Capacitor_SMD:C_1206_3216Metric | ~
C2 | 1 | 10n |  | Capacitor_SMD:C_0805_2012Metric | ~
C4 | 1 | 220p |  | Capacitor_SMD:C_0603_1608Metric | ~
C6 | 1 | 3300p |  | Capacitor_SMD:C_0603_1608Metric | ~
C7 | 1 | 47n |  | Capacitor_SMD:C_0805_2012Metric | ~
C8,C9,C18,C19 | 4 | 10u |  | Capacitor_SMD:C_1206_3216Metric | ~
C10,C12,C13,C14,C15,C16,C17 | 7 | 100n | DNP | Capacitor_THT:C_Disc_D5.0mm_W2.5mm_P2.50mm | ~
C11 | 1 | 1u |  | Capacitor_SMD:C_1206_3216Metric | ~
D1 | 1 | SS34 |  | Diode_SMD:D_SMA | ~
J1 | 1 | USB_B | DNP | USB_B_Samtec_USB-B-S-F-W-TH:SAMTEC_USB-B-S-X-X-TH | https://suddendocs.samtec.com/prints/usb-b-s-x-x-th-x-xx-mkt.pdf
J2 | 1 | Conn_02x04_Top_Bottom | DNP | footprints:Molex_Mini-Fit_Jr_5569-08A2_2x04_P4.20mm_Horizontal | https://www.molex.com/en-us/products/part-detail/39300080?display=pdf
J3 | 1 | Analog | DNP | footprints:Molex_Mini-Fit_Jr_5569-06A2_2x03_P4.20mm_Horizontal | ~
J4 | 1 | ICSP | DNP | Connector_PinHeader_2.54mm:PinHeader_1x05_P2.54mm_Vertical | ~
J5 | 1 | SPI Debug | DNP | Connector_PinSocket_2.54mm:PinSocket_1x03_P2.54mm_Vertical | ~
J6 | 1 | CAN ~{CS} | DNP | Connector_PinSocket_2.54mm:PinSocket_1x01_P2.54mm_Vertical | ~
J7 | 1 | ROM ~{CS} | DNP | Connector_PinSocket_2.54mm:PinSocket_1x01_P2.54mm_Vertical | ~
J8 | 1 | DAC ~{CS} | DNP | Connector_PinSocket_2.54mm:PinSocket_1x02_P2.54mm_Vertical | ~
J9 | 1 | Conn_01x04_Socket | DNP | Connector_PinSocket_2.54mm:PinSocket_1x04_P2.54mm_Vertical | ~
J10 | 1 | +5VA | DNP | Connector_PinSocket_2.54mm:PinSocket_1x01_P2.54mm_Vertical | ~
JP1 | 1 | Prog | DNP | Connector_PinSocket_2.54mm:PinSocket_1x03_P2.54mm_Vertical | ~
JP2 | 1 | Term | DNP | Connector_PinSocket_2.54mm:PinSocket_1x02_P2.54mm_Vertical | ~
L1 | 1 | 150u | DNP | Inductor_SMD:L_Wuerth_WE-PD-Typ-LS_Handsoldering | https://www.we-online.com/components/products/datasheet/7447706151.pdf
R1 | 1 | 10k |  | Resistor_SMD:R_0805_2012Metric | ~
R2 | 1 | 3k24 |  | Resistor_SMD:R_0805_2012Metric | ~
R3 | 1 | 2k7 |  | Resistor_SMD:R_0805_2012Metric | ~
R6,R7,R9,R10,R11 | 5 | 10k | DNP | Resistor_THT:R_Axial_DIN0207_L6.3mm_D2.5mm_P7.62mm_Horizontal | ~
R8 | 1 | 120 |  | Resistor_SMD:R_0805_2012Metric | ~
SW1 | 1 | Reset | DNP | Button_Switch_THT:SW_PUSH-12mm | ~
U1 | 1 | PIC16F1459-IP | DNP | Package_DIP:DIP-20_W7.62mm | http://ww1.microchip.com/downloads/en/DeviceDoc/41639A.pdf
U2 | 1 | MCP2515-I/P | DNP | Package_DIP:DIP-18_W7.62mm | http://ww1.microchip.com/downloads/en/DeviceDoc/21801e.pdf
U3 | 1 | MCP2561-E-P | DNP | Package_DIP:DIP-8_W7.62mm | http://ww1.microchip.com/downloads/en/DeviceDoc/25167A.pdf
U4 | 1 | 25LC160C | DNP | Package_DIP:DIP-8_W7.62mm | http://ww1.microchip.com/downloads/en/DeviceDoc/21832H.pdf
U5 | 1 | TPS5430DDA |  | Package_SO:TI_SO-PowerPAD-8 | http://www.ti.com/lit/ds/symlink/tps5430.pdf
U6,U7 | 2 | L78M05AB |  | Package_TO_SOT_SMD:TO-252-2 | https://www.st.com/resource/en/datasheet/l78m05ab.pdf
U8,U9 | 2 | MCP4912 | DNP | Package_DIP:DIP-14_W7.62mm | http://ww1.microchip.com/downloads/en/DeviceDoc/22250A.pdf

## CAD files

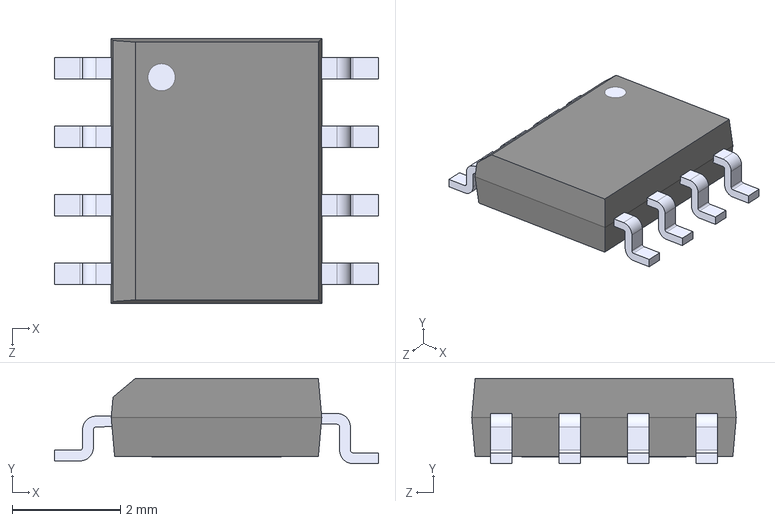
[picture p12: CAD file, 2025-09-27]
hw/3d/AP7375Q-50SP-13/3D/AP7375Q-50SP-13.stp
6.00 x 1.58 x 4.90 mm

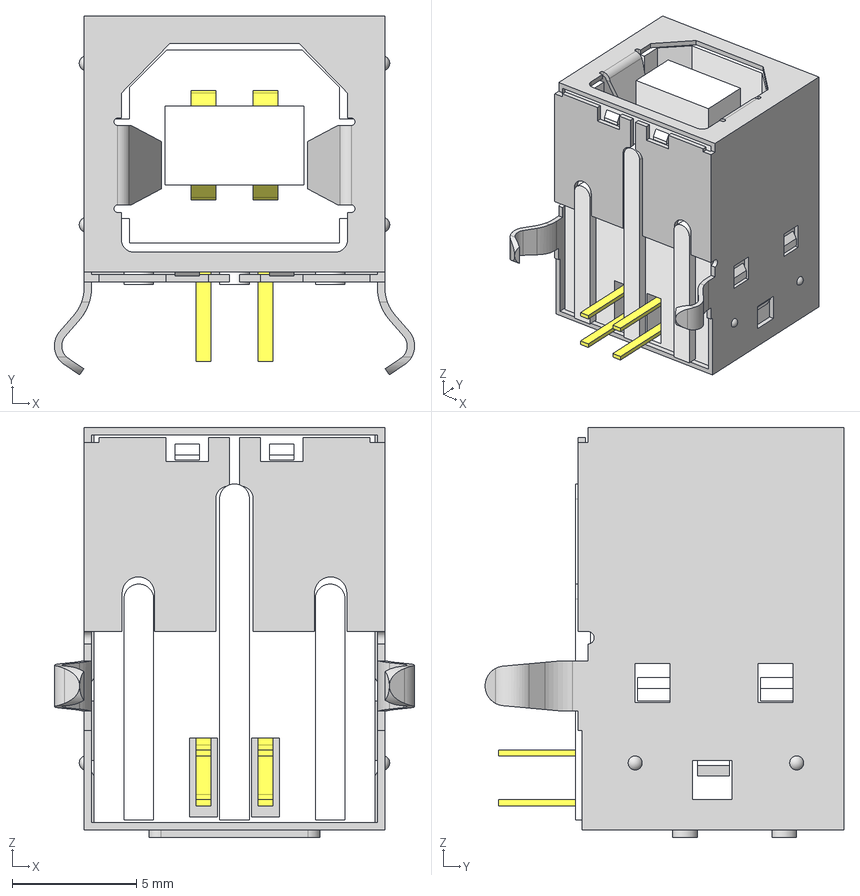
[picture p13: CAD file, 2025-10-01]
hw/elec/footprints/USB_B_Samtec_USB-B-S-F-W-TH/USB-B-S-X-X-TH.step
14.5 x 14.4 x 16.5 mm
USB-B-S-TH_S
USB-B-S-W-TH_B
USB-B-S-TH_P

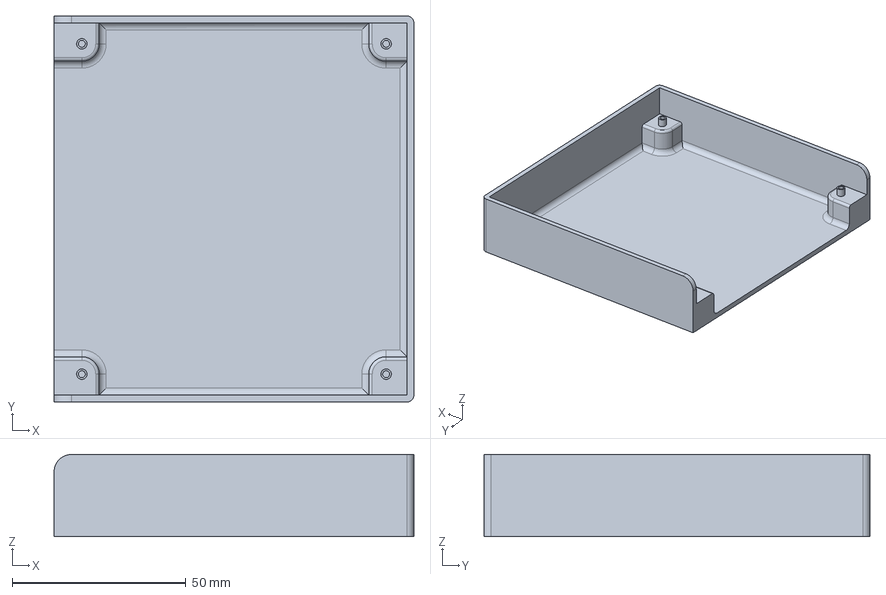
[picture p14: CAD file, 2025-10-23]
mech/bed/bed.FCStd
103.5 x 111.0 x 23.6 mm

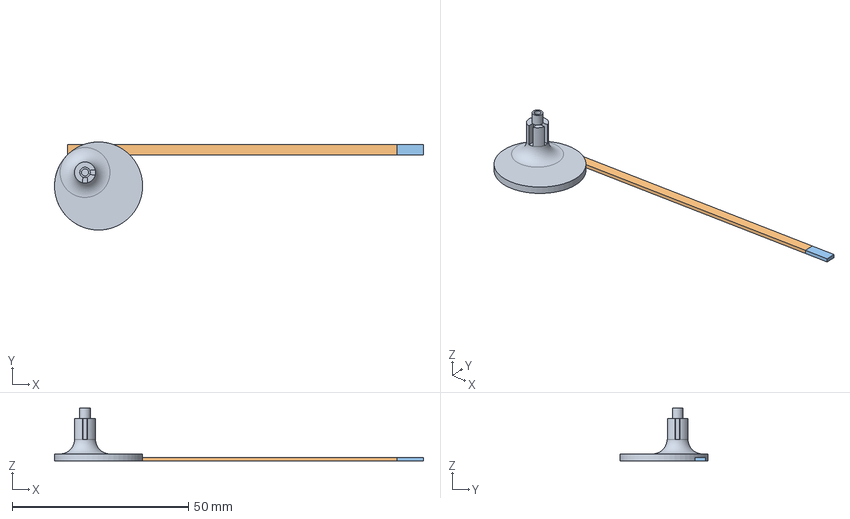
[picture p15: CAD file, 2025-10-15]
mech/standoff/standoff.FCStd
104.7 x 25.0 x 15.0 mm
standoff001
beam x
beam y

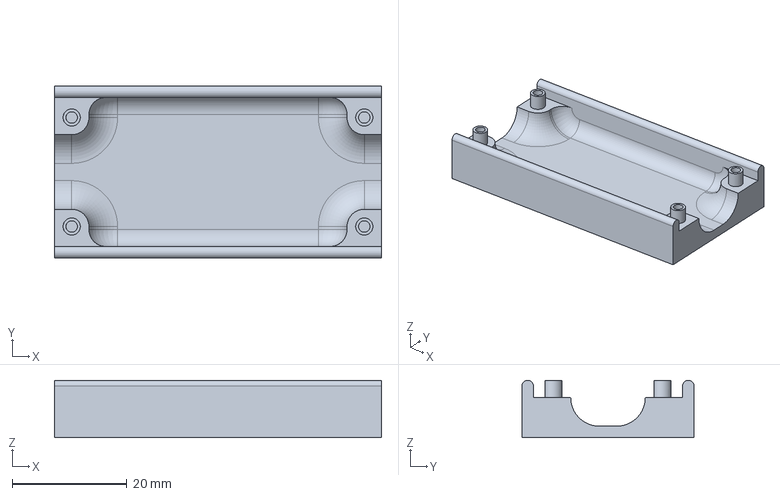
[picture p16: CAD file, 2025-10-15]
mech/usbtin_bed/usbtin_bed.FCStd
57.0 x 30.0 x 10.0 mm

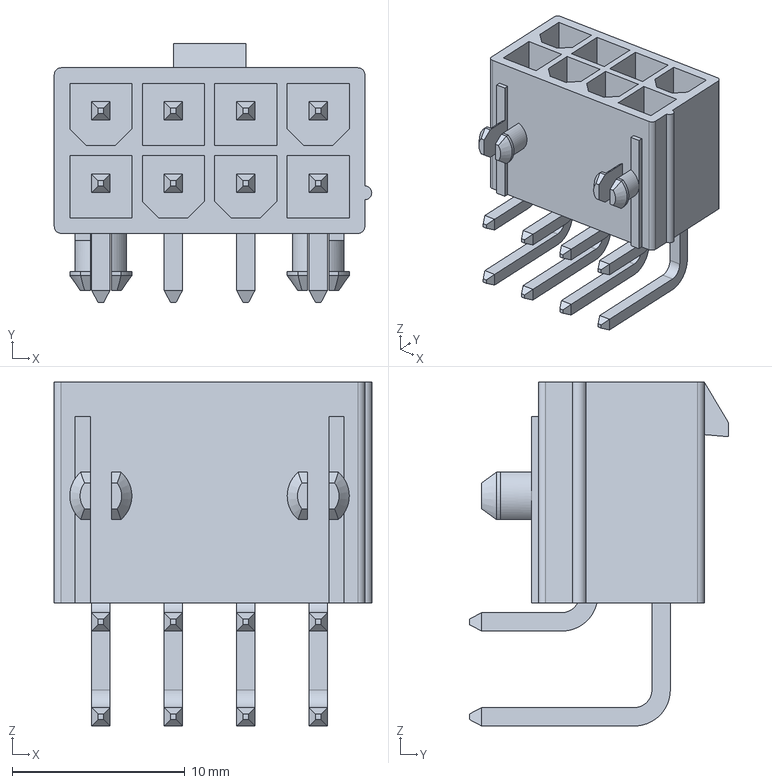
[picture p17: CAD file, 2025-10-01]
hw/elec/footprints/molex_5569/039301080.stp
18.4 x 15.0 x 19.9 mm

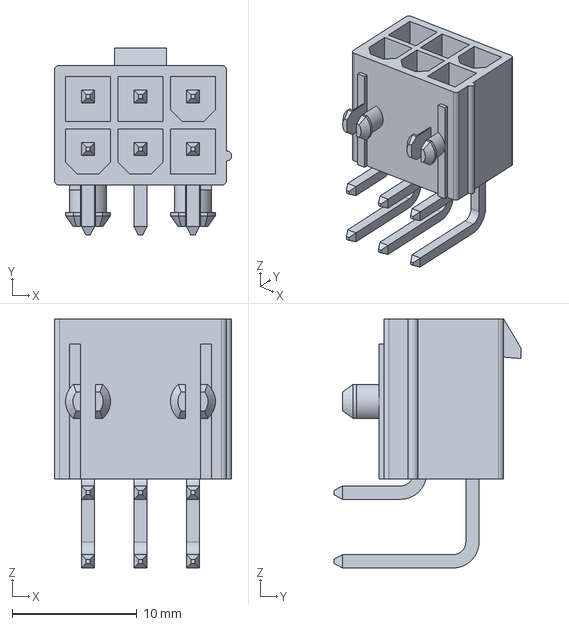
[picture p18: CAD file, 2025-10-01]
hw/elec/footprints/molex_5569/039301060.stp
14.2 x 15.0 x 19.9 mm

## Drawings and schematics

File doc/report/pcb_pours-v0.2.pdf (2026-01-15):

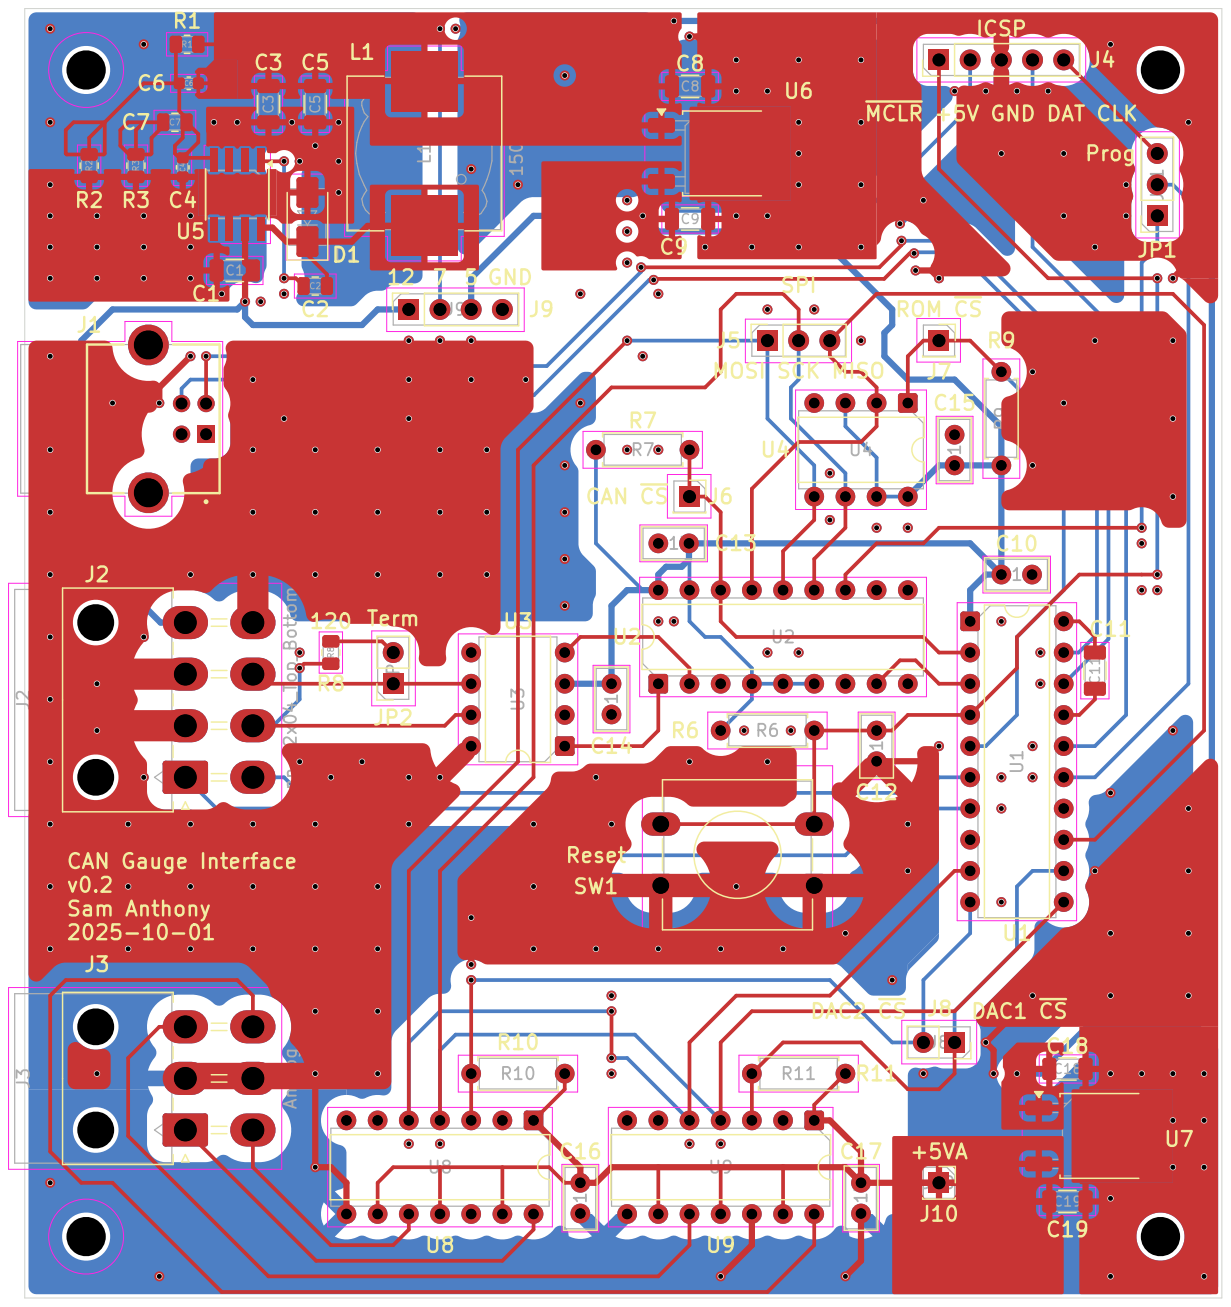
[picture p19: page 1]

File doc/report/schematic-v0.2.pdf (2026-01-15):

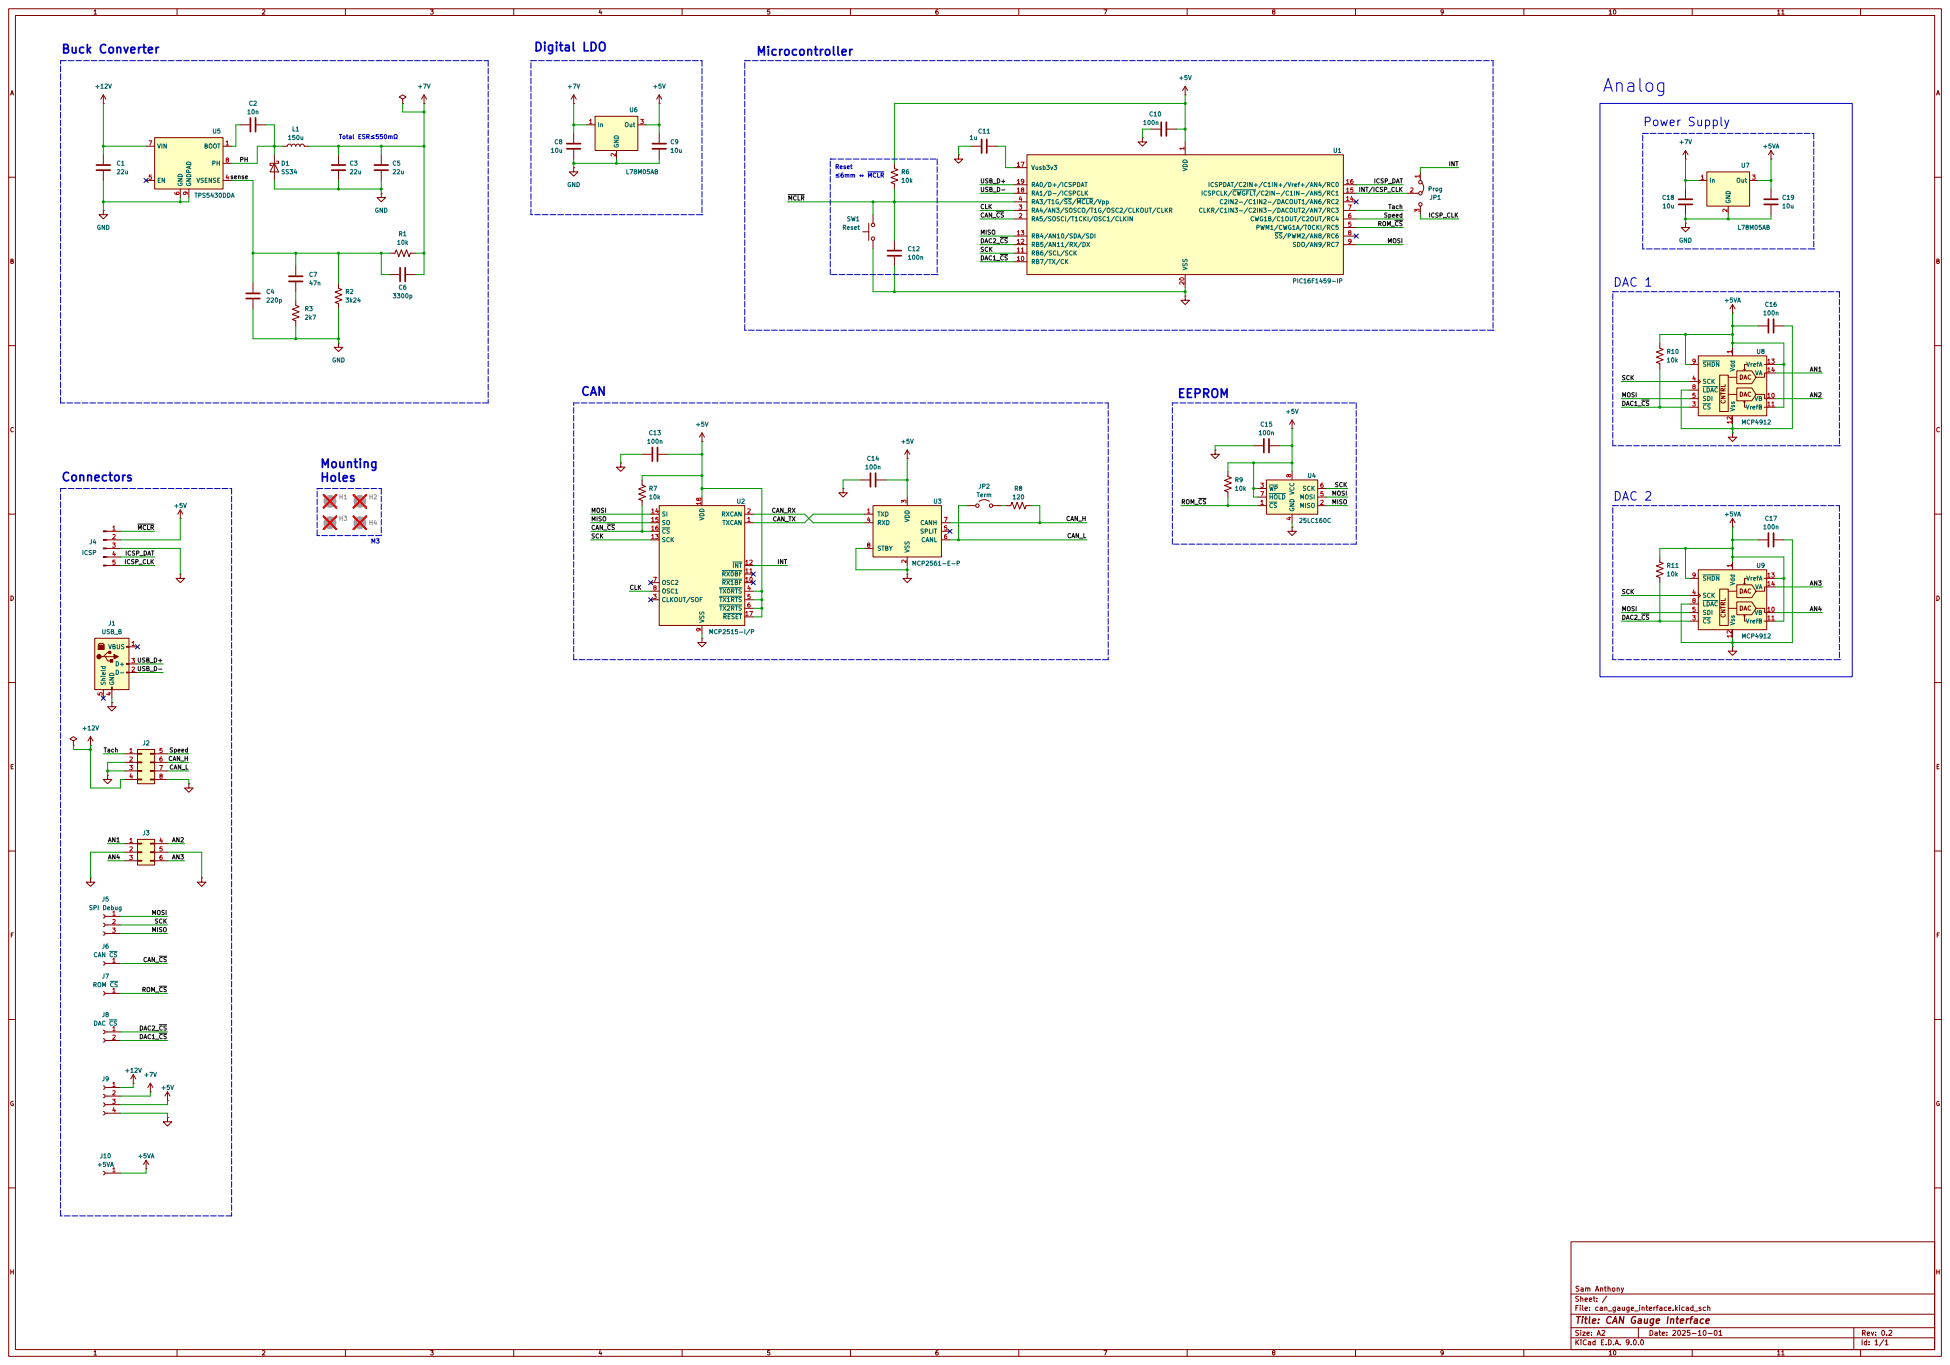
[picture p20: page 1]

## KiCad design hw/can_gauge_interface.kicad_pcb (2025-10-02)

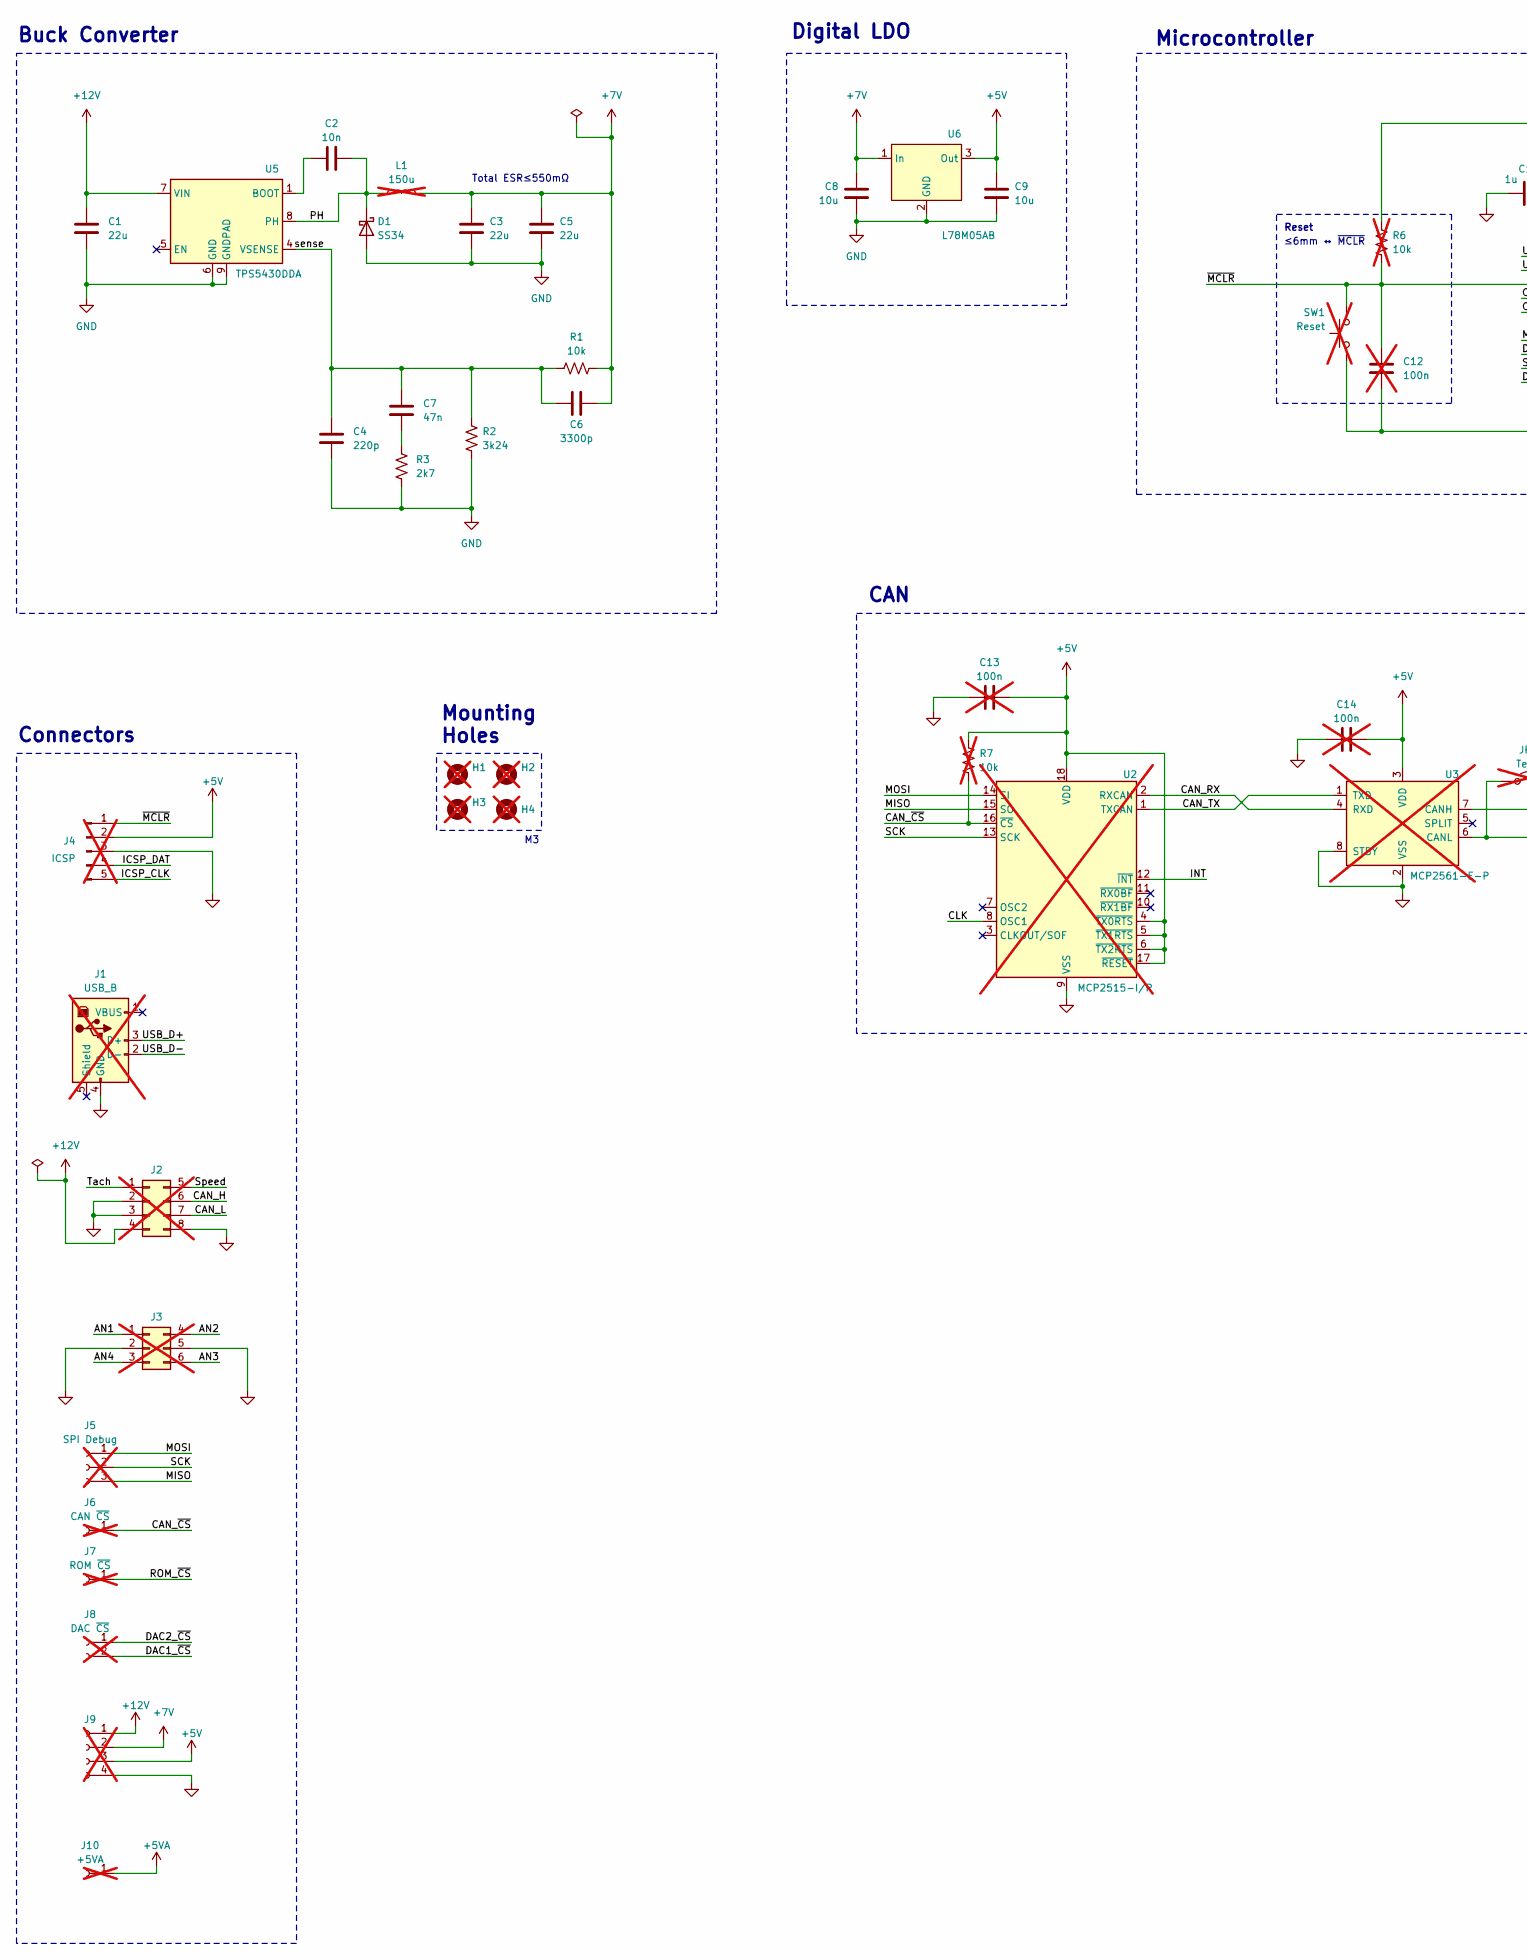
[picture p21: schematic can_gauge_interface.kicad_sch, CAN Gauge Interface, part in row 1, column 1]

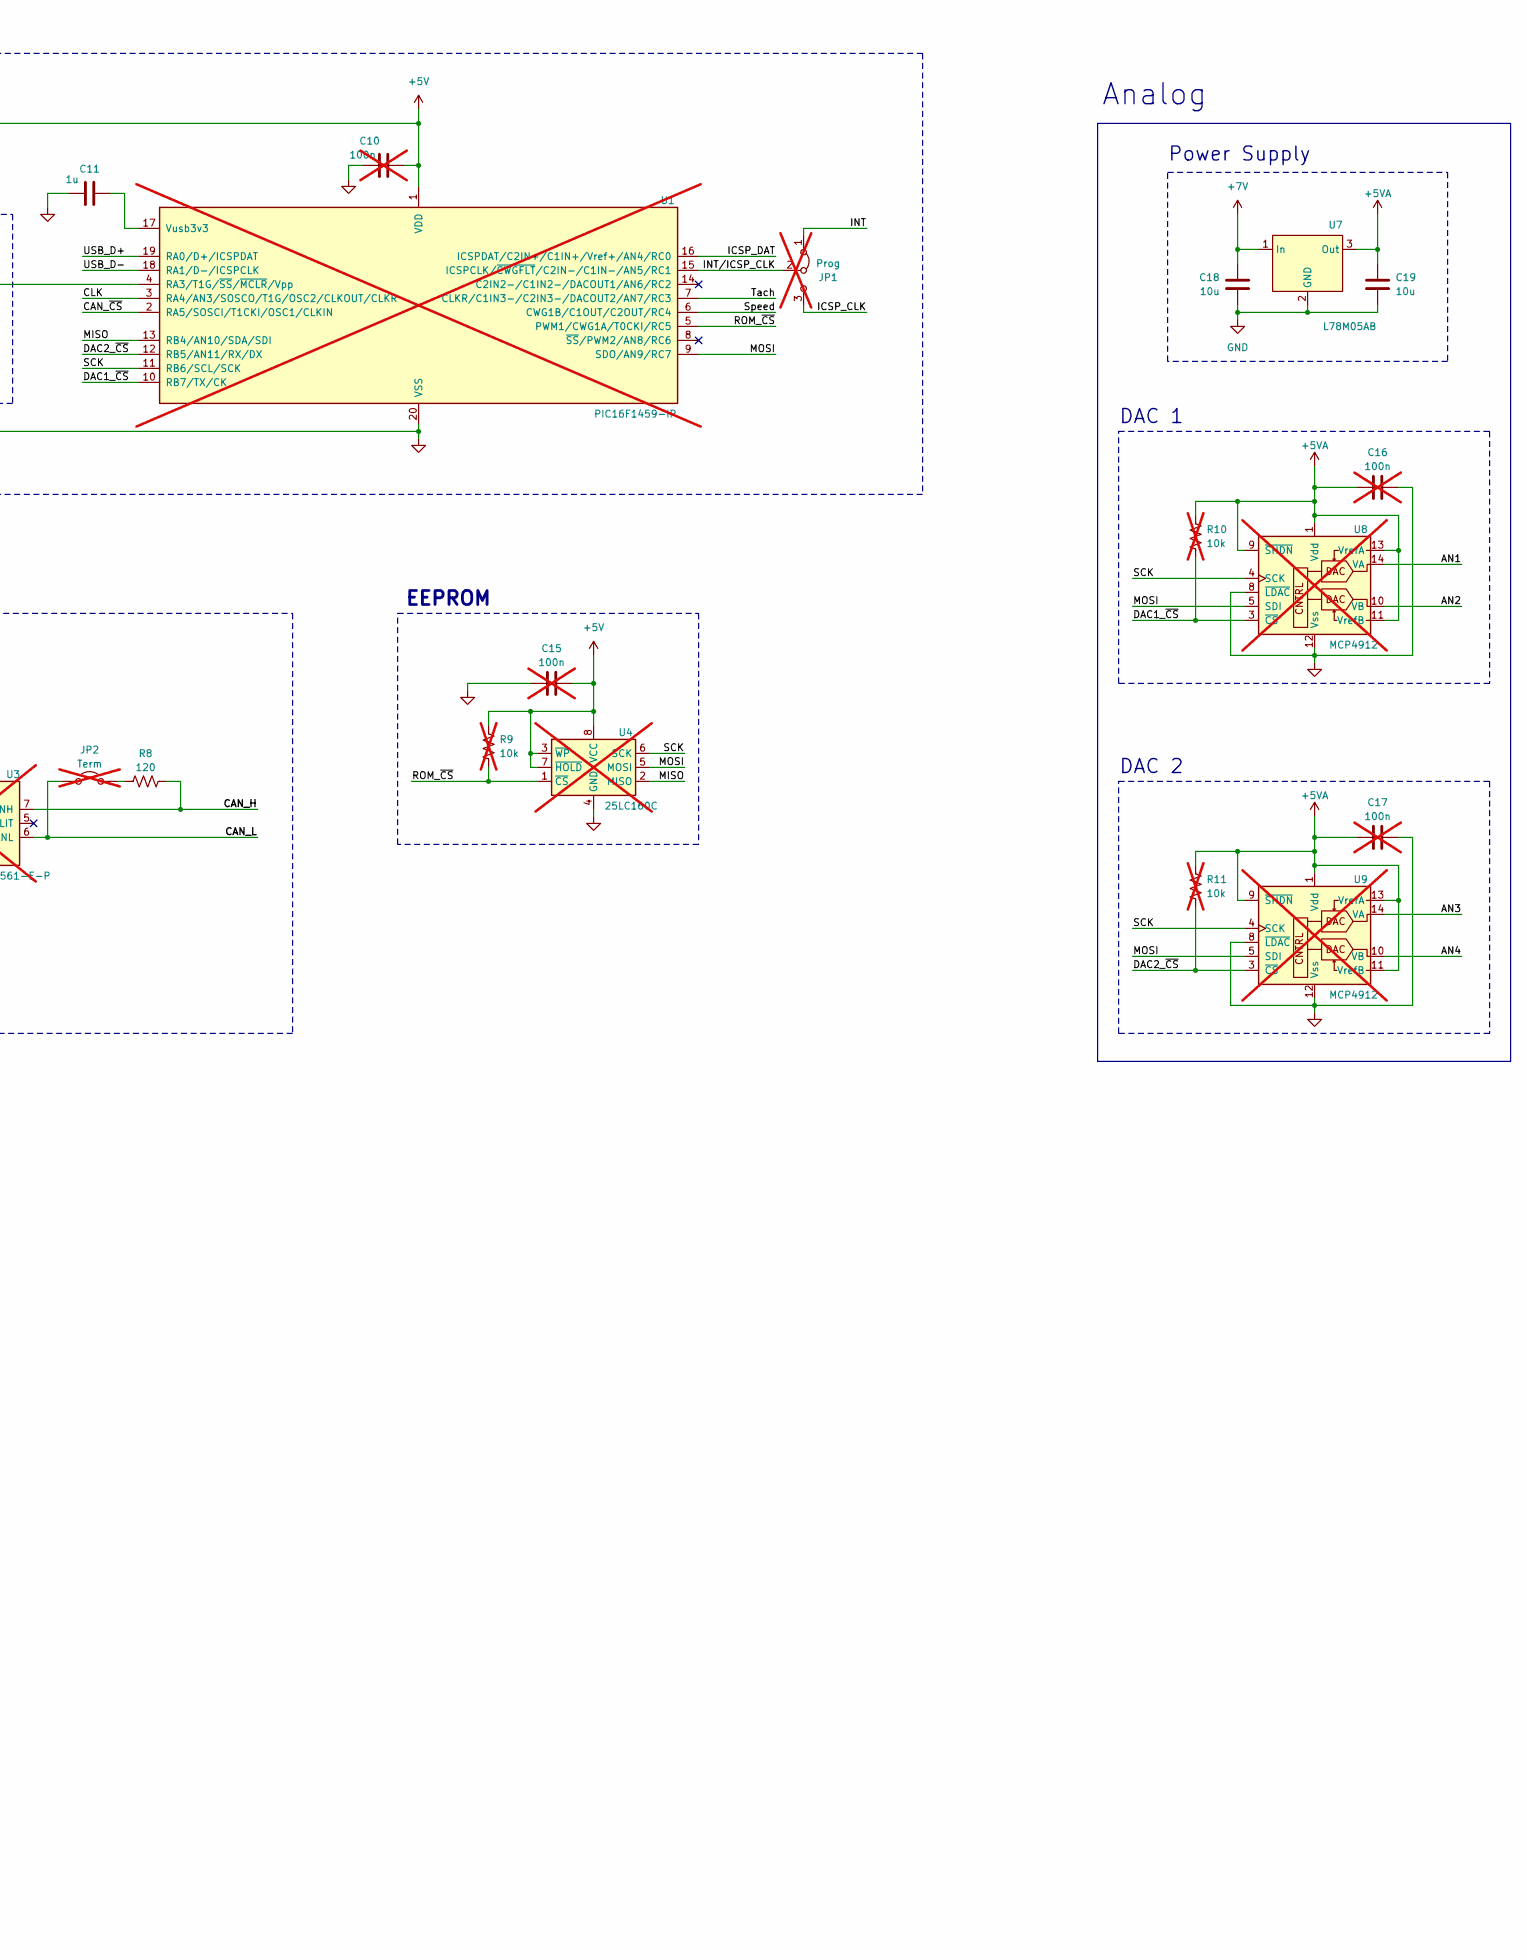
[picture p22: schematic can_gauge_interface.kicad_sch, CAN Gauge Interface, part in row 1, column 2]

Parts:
C1, C3, C5: 22u; C_1206_3216Metric
C2: 10n; C_0805_2012Metric
C4: 220p; C_0603_1608Metric
C6: 3300p; C_0603_1608Metric
C7: 47n; C_0805_2012Metric
C8, C9, C18, C19: 10u; C_1206_3216Metric
C10, C12, C13, C14, C15, C16, C17: 100n; C_Disc_D5.0mm_W2.5mm_P2.50mm; not fitted
C11: 1u; C_1206_3216Metric
D1: SS34; D_SMA
H1, H2, H3, H4: MountingHole; MountingHole_3.2mm_M3_DIN965; not fitted
J1: USB_B; SAMTEC_USB-B-S-X-X-TH; not fitted
J2: Conn_02x04_Top_Bottom; Molex_Mini-Fit_Jr_5569-08A2_2x04_P4.20mm_Horizontal; not fitted
J3: Analog; Molex_Mini-Fit_Jr_5569-06A2_2x03_P4.20mm_Horizontal; not fitted
J4: ICSP; PinHeader_1x05_P2.54mm_Vertical; not fitted
J5: SPI Debug; PinSocket_1x03_P2.54mm_Vertical; not fitted
J6: CAN ~{CS}; PinSocket_1x01_P2.54mm_Vertical; not fitted
J7: ROM ~{CS}; PinSocket_1x01_P2.54mm_Vertical; not fitted
J8: DAC ~{CS}; PinSocket_1x02_P2.54mm_Vertical; not fitted
J9: Conn_01x04_Socket; PinSocket_1x04_P2.54mm_Vertical; not fitted
J10: +5VA; PinSocket_1x01_P2.54mm_Vertical; not fitted
JP1: Prog; PinSocket_1x03_P2.54mm_Vertical; not fitted
JP2: Term; PinSocket_1x02_P2.54mm_Vertical; not fitted
L1: 150u; L_Wuerth_WE-PD-Typ-LS_Handsoldering; not fitted
R1: 10k; R_0805_2012Metric
R2: 3k24; R_0805_2012Metric
R3: 2k7; R_0805_2012Metric
R6, R7, R9, R10, R11: 10k; R_Axial_DIN0207_L6.3mm_D2.5mm_P7.62mm_Horizontal; not fitted
R8: 120; R_0805_2012Metric
SW1: Reset; SW_PUSH-12mm; not fitted
U1: PIC16F1459-IP; DIP-20_W7.62mm; not fitted
U2: MCP2515-I/P; DIP-18_W7.62mm; not fitted
U3: MCP2561-E-P; DIP-8_W7.62mm; not fitted
U4: 25LC160C; DIP-8_W7.62mm; not fitted
U5: TPS5430DDA; TI_SO-PowerPAD-8
U6, U7: L78M05AB; TO-252-2
U8, U9: MCP4912; DIP-14_W7.62mm; not fitted

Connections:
+5V: C9.1, C10.1, C13.2, C14.2, C15.2, J4.2, J9.3, R6.1, R7.1, R9.1, U1.1 (VDD), U2.4 (~TX0RTS), U2.5 (~TX1RTS), U2.6 (~TX2RTS), U2.17 (~RESET), U2.18 (VDD), U3.3 (VDD), U4.3 (~WP), U4.7 (~HOLD), U4.8 (VCC), U6.3 (Out)
+5VA: C16.1, C17.1, C19.1, J10.1, R10.1, R11.1, U7.3 (Out), U8.1 (Vdd), U8.9 (~SHDN), U8.11 (VrefB), U8.13 (VrefA), U9.1 (Vdd), U9.9 (~SHDN), U9.11 (VrefB), U9.13 (VrefA)
+7V: C3.1, C5.1, C6.2, C8.1, C18.1, J9.2, L1.2, R1.2, U6.1 (In), U7.1 (In)
+12V: C1.1, J2.4, J9.1, U5.7 (VIN)
/AN1: J3.1, U8.14 (VA)
/AN2: J3.4, U8.10 (VB)
/AN3: J3.6, U9.14 (VA)
/AN4: J3.3, U9.10 (VB)
/CAN_H: J2.6, R8.2, U3.7 (CANH)
/CAN_L: J2.7, JP2.1 (A), U3.6 (CANL)
/CAN_RX: U2.2 (RXCAN), U3.4 (RXD)
/CAN_TX: U2.1 (TXCAN), U3.1 (TXD)
/CAN_~CS: J6.1, R7.2, U1.2 (RA5/SOSCI/T1CKI/OSC1/CLKIN), U2.16 (~CS)
/CLK: U1.3 (RA4/AN3/SOSCO/T1G/OSC2/CLKOUT/CLKR), U2.8 (OSC1)
/DAC1_~CS: J8.2, R10.2, U1.10 (RB7/TX/CK), U8.3 (~CS)
/DAC2_~CS: J8.1, R11.2, U1.12 (RB5/AN11/RX/DX), U9.3 (~CS)
/ICSP_CLK: J4.5, JP1.3 (B)
/ICSP_DAT: J4.4, U1.16 (ICSPDAT/C2IN+/C1IN+/Vref+/AN4/RC0)
/INT: JP1.1 (A), U2.12 (~INT)
/INT/ICSP_CLK: JP1.2 (C), U1.15 (ICSPCLK/~CWGFLT/C2IN-/C1IN-/AN5/RC1)
/MISO: J5.3, U1.13 (RB4/AN10/SDA/SDI), U2.15 (SO), U4.2 (MISO)
/MOSI: J5.1, U1.9 (SDO/AN9/RC7), U2.14 (SI), U4.5 (MOSI), U8.5 (SDI), U9.5 (SDI)
/PH: C2.2, D1.1 (K), L1.1, U5.8 (PH)
/ROM_~CS: J7.1, R9.2, U1.5 (PWM1/CWG1A/T0CKI/RC5), U4.1 (~CS)
/SCK: J5.2, U1.11 (RB6/SCL/SCK), U2.13 (SCK), U4.6 (SCK), U8.4 (SCK), U9.4 (SCK)
/Speed: J2.5, U1.6 (CWG1B/C1OUT/C2OUT/RC4)
/Tach: J2.1, U1.7 (CLKR/C1IN3-/C2IN3-/DACOUT2/AN7/RC3)
/USB_D+: J1.3 (D+), U1.19 (RA0/D+/ICSPDAT)
/USB_D-: J1.2 (D-), U1.18 (RA1/D-/ICSPCLK)
/sense: C4.1, C6.1, C7.1, R1.1, R2.1, U5.4 (VSENSE)
/~MCLR: C12.1, J4.1, R6.2, SW1.2, U1.4 (RA3/T1G/~SS/~MCLR/Vpp)
GND: C1.2, C3.2, C4.2, C5.2, C8.2, C9.2, C10.2, C11.2, C12.2, C13.1, C14.1, C15.1, C16.2, C17.2, C18.2, C19.2, D1.2 (A), J1.4 (GND), J2.2, J2.3, J2.8, J3.2, J3.5, J4.3, J9.4, R2.2, R3.2, SW1.1, U1.20 (VSS), U2.9 (VSS), U3.2 (VSS), U3.8 (STBY), U4.4 (GND), U5.6 (GND), U5.9 (GNDPAD), U6.2 (GND), U7.2 (GND), U8.8 (~LDAC), U8.12 (Vss), U9.8 (~LDAC), U9.12 (Vss)
unnamed: C7.2, R3.1
unnamed: JP2.2 (B), R8.1
unnamed: C11.1, U1.17 (Vusb3v3)
unnamed: C2.1, U5.1 (BOOT)

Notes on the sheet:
Connectors
Power Supply
Buck Converter
Total ESR≤550mΩ
CAN
Reset
Mounting Holes
EEPROM
Digital LDO
≤6mm ↔ ~{MCLR}
DAC 1
Microcontroller
Analog
DAC 2

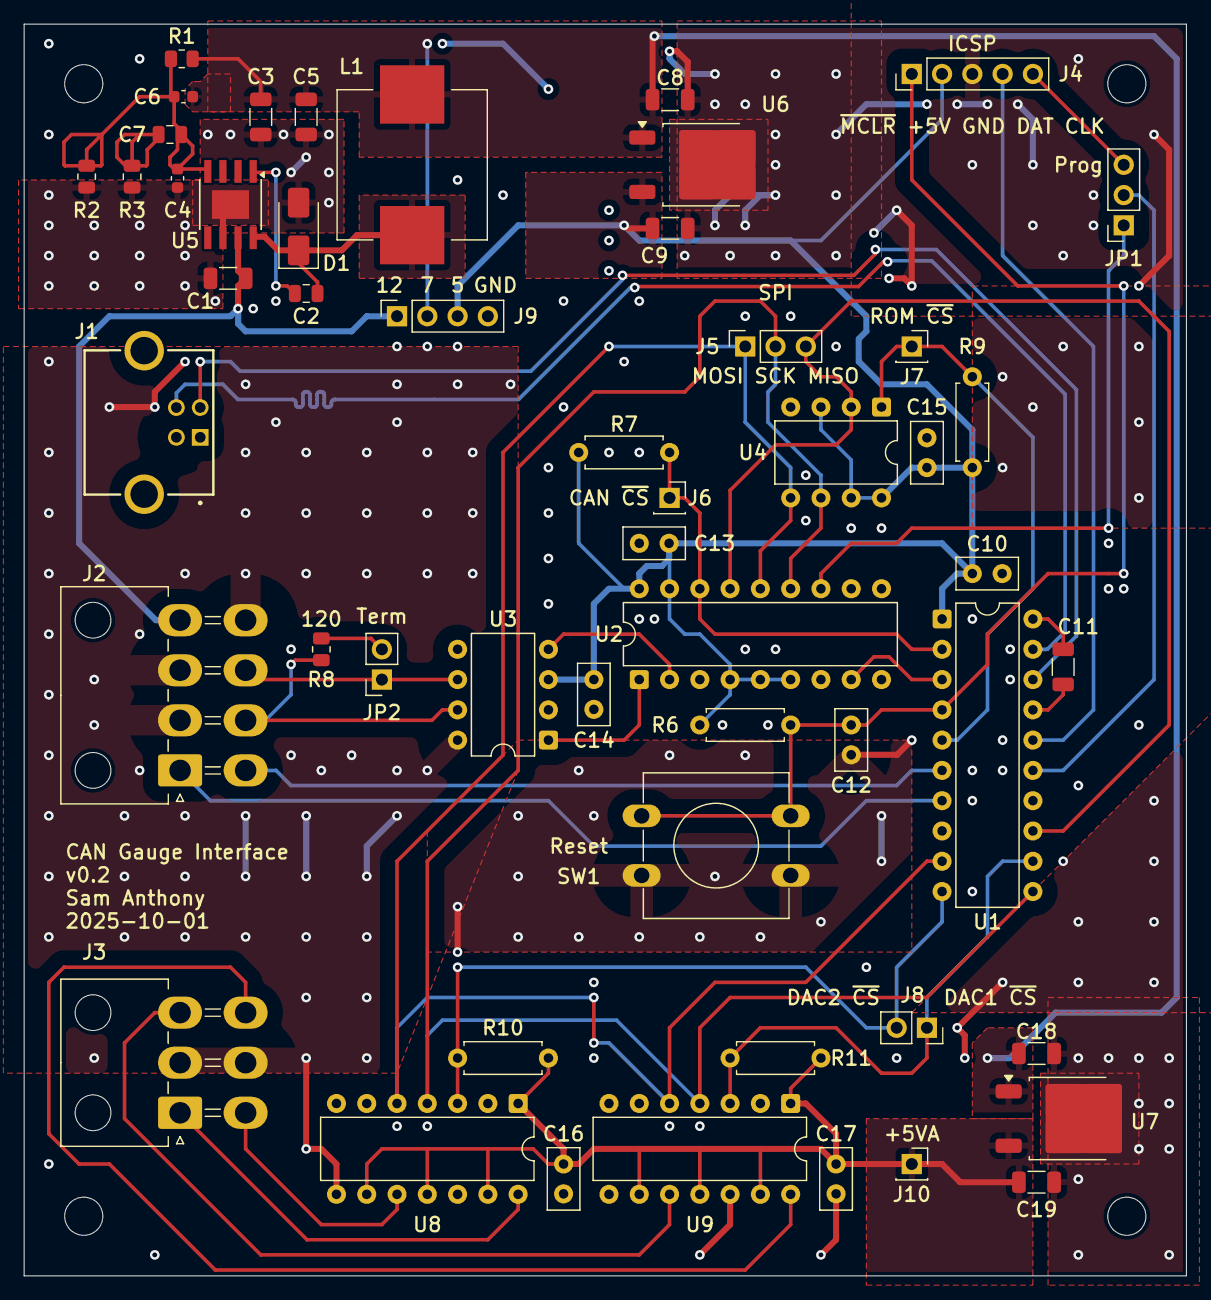
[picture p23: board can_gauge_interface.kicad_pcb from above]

Board: 4 copper layers, 97.5 x 105.0 mm, 56 parts (0 on the bottom side), 36 nets.

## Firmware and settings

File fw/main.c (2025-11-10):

#include <xc.h>

#include <stdbool.h>
#include <stdint.h>
#include <string.h>

#include "system.h"
#include "types.h"
#include "spi.h"
#include "eeprom.h"
#include "dac.h"
#include "can.h"
#include "signal.h"
#include "serial.h"
#include "table.h"

#define ERR __LINE__

// TODO: auto baud detection
#define CAN_TIMING CAN_TIMING_10K

#define TAB_CTRL_CAN_ID 0x1272000 // Table Control Frame ID
#define SIG_CTRL_CAN_ID 0x1272100 // Signal Control Frame ID
#define ERR_CAN_ID 0x1272F00

// Tachometer -- TMR1
// (pulse/min) = 60 * (Fosc/4) / ((pre)*(post)*(2^16 - TMR1))
//  = 60 * (48e6/4) / (8*6*(2^16 - TMR1))
//  = 15000000 / (2^16 - TMR1)
#define TACH_FACTOR 15000000ul
#define TMR1_POST 6u // TMR1 postscaler -- must be multiple of 2
#define MIN_TACH_PULSE_PER_MIN 229u // (pulse/min) >= TACH_FACTOR / (2^16)

// Speedometer -- TMR2
// (pulse/min) = 60 * (Fosc/4) / ((pre)*(post)*(PR2+1)*(period))
// = 60 * (48e6/4) / (64*16*10*(period))
// = 70313 / (period)
#define SPEED_FACTOR 70313ul
#define MIN_SPEED_PULSE_PER_MIN 2u // (pulse/min) >= SPEED_FACTOR / period_max)

#define EDGE_PER_PULSE 2u // rising and falling edge

// Signals
typedef enum {
	SIG_TACH = 0,
	SIG_SPEED,
	SIG_AN1,
	SIG_AN2,
	SIG_AN3,
	SIG_AN4,

	NSIG,
} Signal;

// Table Control filter.
// Used for writing/reading calibration tables.
static const CanId tblCtrlFilter = {
	.isExt = true,
	.eid = TAB_CTRL_CAN_ID};

// Signal Control filter.
// Used for writing/reading the CAN ID and encoding format of  each signal.
// See `doc/datafmt.pdf'.
static const CanId sigCtrlFilter = {
	.isExt = true,
	.eid = SIG_CTRL_CAN_ID};

// Receive buffer 0 mask.
// RXB0 receives Table Control and Signal Control frames.
static const CanId rxb0Mask = {
	.isExt = true,
	.eid = 0x1FFFFF00, // all but LSB
};

// Receive buffer 1 mask.
// RXB1 is used for receiving signals.
// The mask is permissive: all messages are accepted and filtered in software.
static const CanId rxb1Mask = {
	.isExt = true,
	.eid = 0u, // accept all messages
};

// Calibration tables in EEPROM
static const Table tbls[NSIG] = {
	[SIG_TACH] = {0ul*TAB_SIZE}, // tachometer
	[SIG_SPEED] = {1ul*TAB_SIZE}, // speedometer
	[SIG_AN1] = {2ul*TAB_SIZE}, // analog channels...
	[SIG_AN2] = {3ul*TAB_SIZE},
	[SIG_AN3] = {4ul*TAB_SIZE},
	[SIG_AN4] = {5ul*TAB_SIZE},
};

// EEPROM address of encoding format structure for each signal.
// Each of these addresses point to a SigFmt structure in the EEPROM.
static const EepromAddr sigFmtAddrs[NSIG] = {
	[SIG_TACH] = NSIG*TAB_SIZE + 0ul*SER_SIGFMT_SIZE, // tachometer
	[SIG_SPEED] = NSIG*TAB_SIZE + 1ul*SER_SIGFMT_SIZE, // speedometer
	[SIG_AN1] = NSIG*TAB_SIZE + 2ul*SER_SIGFMT_SIZE, // analog channels...
	[SIG_AN2] = NSIG*TAB_SIZE + 3ul*SER_SIGFMT_SIZE,
	[SIG_AN3] = NSIG*TAB_SIZE + 4ul*SER_SIGFMT_SIZE,
	[SIG_AN4] = NSIG*TAB_SIZE + 5ul*SER_SIGFMT_SIZE,
};

// Encoding format and CAN ID of each signal
static volatile SigFmt sigFmts[NSIG];

static volatile U16 tmr1Start = 0u;
static volatile U16 tmr2Period = 0u;

// Load signals' encoding formats and CAN IDs from EEPROM
static Status
loadSigFmts(void) {
	U8 oldGie, k;
	Status status;

	// Disable interrupts so the volatile address pointers can be passed safely
	oldGie = GIE;
	GIE = 0;

	for (k = 0u; k < NSIG; k++) {
		status = serReadSigFmt(sigFmtAddrs[k], (SigFmt *)&sigFmts[k]);
		if (status != OK) {
			INTCONbits.GIE = oldGie; // restore previous interrupt setting
			return ERR;
		}
	}

	// Restore previous interrupt setting
	INTCONbits.GIE = oldGie;

	return OK;
}

// Transmit an error code (typically a line number) to the CAN bus.
static void
txErrFrame(Status err) {
	CanFrame frame;

	frame.id = (CanId){.isExt = true, .eid = ERR_CAN_ID};
	frame.rtr = false;
	frame.dlc = 2u;
	frame.data[0u] = (err >> 8u) & 0xFF;
	frame.data[1u] = (err >> 0u) & 0xFF;
	(void)canTx(&frame);
}

static void
reset(void) {
	_delay(100000);
	asm("RESET");
}

void
main(void) {
	Status status;

	sysInit();
	spiInit();
	canInit();
	dacInit();
	eepromInit();

	// Setup MCP2515 CAN controller
	canSetBitTiming(CAN_TIMING);
	canSetMask0(&rxb0Mask); // RXB0 receives control messages
	canSetFilter0(&tblCtrlFilter); // Table Control Frames
	canSetFilter1(&sigCtrlFilter); // Signal Control Frames
	canSetMask1(&rxb1Mask); // RXB1 receives signal values
		// RXB1 messages are filtered in software
	canIE(true); // enable interrupts on MCP2515's INT pin
	canSetMode(CAN_MODE_NORMAL);

	// Load signals' encoding formats and CAN IDs from EEPROM
	status = loadSigFmts();
	if (status != OK) {
		txErrFrame(status);
		reset();
	}

	// Setup TMR1 for tachometer
	T1CON = 0x31; // source=Fosc/4, prescaler=1:8, enable=1

	// Setup TMR2 for speedometer
	T2CON = 0x7F; // postscaler=1:16, enable=1, prescaler=1:64
	PR2 = 10u-1u; // period = PR2+1

	// Enable interrupts
	INTCON = 0x00; // clear flags
	INTEDG = 0; // interrupt on falling edge of INT pin
	INTE = 1; // enable INT pin
	PEIE = 1; // enable peripheral interrupts
	GIE = 1; // enable global interrupts

	for (;;) {

	}
}

// Handle a Table Control Frame.
// See `doc/datafmt.pdf'
static Status
handleTblCtrlFrame(const CanFrame *frame) {
	U8 tab, row;
	U32 key;
	U16 val;
	Status status;
	CanFrame response;

	// Extract table and row indices from ID
	tab = (frame->id.eid & 0xE0) >> 5u;
	row = frame->id.eid & 0x1F;
	if (tab >= NSIG || row >= TAB_ROWS) {
		return ERR;
	}

	if (frame->rtr) { // REMOTE
		status = tabRead(&tbls[tab], row, &key, &val);
		if (status != OK) {
			return ERR;
		}
		response.id = (CanId){
			.isExt = true,
			.eid = TAB_CTRL_CAN_ID | ((tab << 5u) & 0xE0) | (row & 0x1F)};
		response.rtr = false;
		response.dlc = 6u;
		serU32Be(response.data, key);
		serU16Be(response.data+4u, val);
		return canTx(&response);
	} else { // DATA
		if (frame->dlc != 6u) {
			return ERR;
		}
		key = deserU32Be(frame->data);
		val = deserU16Be(frame->data+4u);
		return tabWrite(&tbls[tab], row, key, val);
	}
}

// Transmit the response to a Signal Control REMOTE FRAME.
// The response is a Signal Control DATA FRAME containing the CAN ID
// and encoding format of the requested signal.
static Status
respondSigCtrl(Signal sig) {
	const volatile SigFmt *sigFmt;
	CanFrame response;

	if (sig >= NSIG) {
		return ERR;
	}
	sigFmt = &sigFmts[sig];

	response.id = (CanId){
		.isExt = true,
		.eid = SIG_CTRL_CAN_ID | (sig & 0xF),
	};
	response.rtr = false;
	response.dlc = 7u;

	// SigId
	if (sigFmt->id.isExt) { // extended
		serU32Be(response.data, sigFmt->id.eid & 0x1FFFFFFF);
		response.data[0u] |= 0x80; // EXIDE=1

	} else { // standard
		serU32Be(response.data, sigFmt->id.sid & 0x7FF);
	}

	// Encoding
	response.data[4u] = sigFmt->start;
	response.data[5u] = sigFmt->size;
	response.data[6u] = (U8)((sigFmt->order & 0x1) << 7u)
		| (U8)((sigFmt->isSigned) ? 0x40 : 0x00);

	return canTx(&response);
}

// Set the CAN ID and encoding format of a signal in response
// to a Signal Control DATA FRAME.
static Status
setSigFmt(const CanFrame *frame) {
	Signal sig;
	SigFmt sigFmt;
	Status status;

	// Extract signal number from ID
	sig = frame->id.eid & 0xF;
	if (sig >= NSIG) {
		return ERR;
	}

	// Prepare to unpack DATA FIELD
	if (frame->dlc != 7u) {
		return ERR;
	}

	// Unpack SigId
	if (frame->data[0u] & 0x80) { // EXIDE
		// Extended
		sigFmt.id.isExt = true;
		sigFmt.id.eid = deserU32Be(frame->data) & 0x1FFFFFFF;
	} else {
		// Standard
		sigFmt.id.isExt = false;
		sigFmt.id.sid = deserU16Be(frame->data+2u) & 0x7FF;
	}

	// Unpack Encoding
	sigFmt.start = frame->data[4u];
	sigFmt.size = frame->data[5u];
	sigFmt.order = (frame->data[6u] & 0x80) ? LITTLE_ENDIAN : BIG_ENDIAN;
	sigFmt.isSigned = frame->data[6u] & 0x40;

	// Save to EEPROM
	status = serWriteSigFmt(sigFmtAddrs[sig], &sigFmt);
	if (status != OK) {
		return ERR;
	}

	// Update copy in RAM
	sigFmts[sig] = sigFmt;

	return OK;
}

// Handle a Signal Control Frame.
// See `doc/datafmt.pdf'
static Status
handleSigCtrlFrame(const CanFrame *frame) {
	Signal sig;

	if (frame->rtr) { // REMOTE
		sig = frame->id.eid & 0xF;
		return respondSigCtrl(sig); // respond with the signal's CAN ID and encoding format
	} else { // DATA
		return setSigFmt(frame);
	}
}

// Set frequency of tachometer output signal.
static void
driveTach(U16 pulsePerMin) {
	if (pulsePerMin < MIN_TACH_PULSE_PER_MIN) {
		TMR1IE = 0;
	} else {
		TMR1IE = 1;
		tmr1Start = (((U32)1ul<<16u) - (U32)TACH_FACTOR / (U32)pulsePerMin) & 0xFFFF;
	}
}

// Set frequency of speedometer output signal.
static void
driveSpeed(U16 pulsePerMin) {
	if (pulsePerMin < MIN_SPEED_PULSE_PER_MIN) {
		TMR2IE = 0;
	} else {
		TMR2IE = 1;
		tmr2Period = ((U32)SPEED_FACTOR / pulsePerMin) & 0xFFFF;
	}
}

// Generate the output signal being sent to one of the gauges.
// Raw is the raw signal value extracted from a CAN frame.
static Status
driveGauge(Signal sig, I32 raw) {
	Status status;
	U16 val;

	if (sig >= NSIG) {
		return ERR;
	}

	// Lookup gauge waveform value in EEPROM table
	status = tabLookup(&tbls[sig], raw, &val);
	if (status != OK) {
		return ERR;
	}

	// TODO: remove
	CanFrame frame;
	frame.id = (CanId){.isExt=false, .sid=0x123};
	frame.rtr = false;
	frame.dlc = 7u;
	frame.data[0u] = sig & 0xFF; // signal
	U32 uraw = *(U32 *)&raw;
	serU32Be(frame.data+1, uraw); // key
	serU16Be(frame.data+5, val); // val
	canTx(&frame);

	switch (sig) {
	case SIG_TACH:
		driveTach(val);
		break;
	case SIG_SPEED:
		driveSpeed(val);
		break;
	case SIG_AN1:
		dacSet1a(val);
		break;
	case SIG_AN2:
		dacSet1b(val);
		break;
	case SIG_AN3:
		dacSet2a(val);
		break;
	case SIG_AN4:
		dacSet2b(val);
		break;
	default:
		return ERR; // invalid signal
	}

	// TODO
	return OK;
}

// Handle a frame potentially holding a signal value.
static Status
handleSigFrame(const CanFrame *frame) {
	Status status, result;
	Signal sig;
	I32 raw;

	result = OK;

	// Search for signal with this ID
	// Exhaustive because message may contain multiple signals.
	for (sig = 0u; sig < NSIG; sig++) {
		if (canIdEq(&frame->id, (const CanId *)&sigFmts[sig].id)) {
			// Extract raw signal value from frame
			status = sigPluck((const SigFmt *)&sigFmts[sig], frame, &raw);
			if (status == OK) {
				status = driveGauge(sig, raw); // generate output signal
			}
			result |= status;
		}
	}

	return result;
}

void
__interrupt() isr(void) {
	static U8 tmr1Ctr = 0u;
	static U16 tmr2Ctr = 0u;

	U8 rxStatus;
	CanFrame frame;
	Status status;

	if (INTF) { // CAN interrupt
		rxStatus = canRxStatus();
		switch (rxStatus & 0x7) { // check filter hit
		case 0u: // RXF0: calibration table control
			canReadRxb0(&frame);
			status = handleTblCtrlFrame(&frame);
			if (status != OK) {
				txErrFrame(status);
			}
			break;
		case 1u: // RXF1: signal ID control
			canReadRxb0(&frame);
			status = handleSigCtrlFrame(&frame);
			if (status != OK) {
				txErrFrame(status);
			}
			break;
		default: // message in RXB1
			canReadRxb1(&frame);
			(void)handleSigFrame(&frame);
		}
		INTF = 0; // clear flag
	}
	if (TMR1IF) { // tachometer
		if (++tmr1Ctr >= (TMR1_POST/EDGE_PER_PULSE)) {
			tmr1Ctr = 0u;
			TACH_PIN ^= 1; // toggle tach output
		}
		TMR1H = (tmr1Start>>8u)&0xFF; // reset timer
		TMR1L = (tmr1Start>>0u)&0xFF;
		TMR1IF = 0;
	}
	if (TMR2IF) { // speedometer
		if (++tmr2Ctr >= (tmr2Period/EDGE_PER_PULSE)) {
			tmr2Ctr = 0u;
			SPEED_PIN ^= 1; // toggle speedometer output
		}
		TMR2IF = 0;
	}
}

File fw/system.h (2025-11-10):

#ifndef SYSTEM_H
#define SYSTEM_H

#include "fixed_address_memory.h"

// Pins
#define TACH_PIN RC3 // tachometer
#define TACH_TRIS TRISC3
#define SPEED_PIN RC4 // speedometer
#define SPEED_TRIS TRISC4

// TRIS
enum {
	OUT = 0,
	IN = 1,
};

void sysInit(void);

#endif // SYSTEM_H

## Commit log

2025-08-16 spi and eeprom modules
2025-08-16 add device and compiler to header comments
2025-09-07 power budget
    [power.ods]
2025-09-07 power supply schematic
    [can_gauge_interface.kicad_pcb, can_gauge_interface.kicad_sch, power_budget.ods]
2025-09-07 schematic: MCLR, USB, ICSP
    [can_gauge_interface.kicad_sch]
2025-09-07 schematic: EEPROM
    [can_gauge_interface.kicad_sch]
2025-09-07 schematic: CAN
    [can_gauge_interface.kicad_sch]
2025-09-08 schematic: connectors
    [can_gauge_interface.kicad_sch]
2025-09-08 schematic: spi debug header
    [can_gauge_interface.kicad_sch]
2025-09-08 more debug headers
    [can_gauge_interface.kicad_sch]
2025-09-08 schematic: CAN termination jumper
    [can_gauge_interface.kicad_sch]
2025-09-19 hw: digital and analog LDOs
    [can_gauge_interface.kicad_sch, power_budget.ods, power_supply.ods]
2025-09-19 hw: 6v6 debug pin
    [can_gauge_interface.kicad_sch]
2025-09-19 hw: connected pic gpios
    [can_gauge_interface.kicad_sch]
2025-09-19 hw: fixed erc warnings
    [can_gauge_interface.kicad_sch]
2025-09-20 buck converter layout and routing
    [can_gauge_interface.kicad_pcb, can_gauge_interface.kicad_sch]
2025-09-20 analog ldo layout and routing
    [can_gauge_interface.kicad_pcb]
2025-09-20 analog routing
    [can_gauge_interface.kicad_pcb, can_gauge_interface.kicad_sch]
2025-09-20 digital ldo layout and routing
    [can_gauge_interface.kicad_pcb]
2025-09-20 tht decoupling caps
    [can_gauge_interface.kicad_pcb, can_gauge_interface.kicad_sch]
2025-09-20 dac pullup layout
    [can_gauge_interface.kicad_pcb]
2025-09-20 4 layer stackup and CAN routing
    [can_gauge_interface.kicad_pcb]
2025-09-20 spi routing
    [can_gauge_interface.kicad_pcb, can_gauge_interface.kicad_sch]
2025-09-20 int pin routing
    [can_gauge_interface.kicad_pcb]
2025-09-20 CAN_CS routing
    [can_gauge_interface.kicad_pcb, can_gauge_interface.kicad_sch]
2025-09-20 icsp routing
    [can_gauge_interface.kicad_pcb]
2025-09-20 usb data routing
    [can_gauge_interface.kicad_pcb]
2025-09-20 speed and tach routing
    [can_gauge_interface.kicad_pcb]
2025-09-20 connected buck to conn pin
    [can_gauge_interface.kicad_pcb, can_gauge_interface.kicad_sch]
2025-09-20 dac spi routing
    [can_gauge_interface.kicad_pcb, can_gauge_interface.kicad_sch]
2025-09-20 move sck away from analog
    [can_gauge_interface.kicad_pcb]
2025-09-20 mounting hole placement
    [can_gauge_interface.kicad_pcb]
2025-09-20 edge cuts
    [can_gauge_interface.kicad_pcb]
2025-09-22 moved analog
    [can_gauge_interface.kicad_pcb]
2025-09-22 gnd vias
    [can_gauge_interface.kicad_pcb]
2025-09-22 drc warnings
    [can_gauge_interface.kicad_pcb, can_gauge_interface.kicad_sch]
2025-09-22 gnd pours
    [can_gauge_interface.kicad_pcb]
2025-09-27 psu ic 3d models
    [AP7375Q-50SP-13.stp, can_gauge_interface.kicad_pcb, can_gauge_interface.kicad_sch]
2025-09-27 tht quote
    [bom.csv, bom_jlcpcb.csv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]
2025-09-27 schematic: tps5430 buck
    [can_gauge_interface.kicad_sch, power_supply.ods]
2025-09-27 schematic: ldos
    [can_gauge_interface.kicad_sch]
2025-09-27 schemtic: removed DNP flags
    [can_gauge_interface.kicad_sch]
2025-09-27 wurth usb connector symbol
    [USB_B_Wurth_61400416121.stp, can_gauge_interface.kicad_sch]
2025-09-27 board setup
    [can_gauge_interface.kicad_sch]
2025-09-27 buck layout
    [can_gauge_interface.kicad_pcb, can_gauge_interface.kicad_sch]
2025-09-27 ldo layout
    [can_gauge_interface.kicad_pcb]
2025-09-27 can layout
    [can_gauge_interface.kicad_pcb]
2025-09-28 pic layout
    [can_gauge_interface.kicad_pcb, can_gauge_interface.kicad_sch]
2025-09-29 tht passives
    [can_gauge_interface.kicad_pcb, can_gauge_interface.kicad_sch]
2025-09-29 buck routing
    [can_gauge_interface.kicad_pcb]
2025-09-29 more routing
    [can_gauge_interface.kicad_pcb, can_gauge_interface.kicad_sch]
2025-10-01 tune usb trace length
    [bom.csv, can_gauge_interface.kicad_pcb, can_gauge_interface.kicad_sch]
2025-10-01 removed usb vbus
    [can_gauge_interface.kicad_pcb, can_gauge_interface.kicad_sch]
2025-10-01 manufacturing files
    [bom.csv, bom_jlcpcb.csv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]
2025-10-01 connector 3d models
    [039301060.stp, 039301080.stp, USB-B-S-F-W-TH.stp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]
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2025-10-04 CAN filter- and mask-setting functions
2025-10-13 midterm report: pcb design
2025-10-14 remove deprecated power supply doc
2025-10-15 usbtin bed and standoff models
    [039301060.stp, 039301080.stp, AP7375Q-50SP-13.stp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]
2025-10-15 move hw/ back to top level
    [039301060.stp, 039301080.stp, AP7375Q-50SP-13.stp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]
2025-10-23 board for bed
    [bed.FCStd]
2025-10-25 CAN frame format doc
2025-10-25 handle ID Control Frames
2025-10-25 fix CAN ID format
    [can.c]
2025-10-27 handle ID Control frames (wip)
2025-11-01 extract big-endian signals from frames
2025-11-01 extract little-endian signals from frames
2025-11-01 extract signal from received frames
2025-11-07 respond to Signal Control REMOTE FRAME
2025-11-07 handle Signal Control DATA FRAME
2025-11-07 fix bug in CAN ID packing
    [can.c]
2025-11-07 transmit line number on error
    [can.c, main.c]
2025-11-07 handle Table Control frame
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2025-11-08 swap signal byte_order to reflect amended dbc spec
    [main.c]
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2025-11-08 can: fix bug in packID(); add retry delay
    [can.c]
2025-11-10 use short register names
    [dac.h, main.c]
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2025-12-15 cal: example dbc and csv files
    [ect.csv, speed.csv, tach.csv]

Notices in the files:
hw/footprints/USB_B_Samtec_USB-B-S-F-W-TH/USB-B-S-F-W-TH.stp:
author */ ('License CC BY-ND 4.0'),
